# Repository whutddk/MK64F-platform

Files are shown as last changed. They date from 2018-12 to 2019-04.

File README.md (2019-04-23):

# mk64f-platform

A PCB platform of Arm (NXP-Kinetis) + FPGA (Xilinx-Aritx-7)

------------------------------------

### Construction
* doc 
  - designDoc(some document from manufacturer may be replaced by link )
  - referDoc(introduce of the board and design requirement)
* outputFile (output design file as pdf format)
* PCB(altium designer source file)

### Version List
* 0-1
* 0-2
* 0-3
* 0-4
* 1-1
* 1-3-5
* 3-1
* 4-3-2
* 4-3-5
* 5-2-0

##  Apache 2.0 for all and only my design

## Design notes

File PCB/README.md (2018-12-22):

# mk64f-platform

## place all pcb file here

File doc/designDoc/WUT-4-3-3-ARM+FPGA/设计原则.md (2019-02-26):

# Arm+FPGA原理验证

* 新设计需求
    - 摄像头CSI接口
    - 斩波电源

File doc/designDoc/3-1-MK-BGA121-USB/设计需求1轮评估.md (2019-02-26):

# USB迷你平台第一轮评估

* JTAG-mini10接口

* USB
    - MK64F公头

* 附加外设接口
    - CAN接口仅排针

* 电源
    - USB

* 外设
    - LED
    - 按键
    - 拨码开关

* 封装 
    - BGA
    - 小qfp

* PMOD
    - 完整全功能

* 可选项
    - 小Arduino排针口
    - TF卡口

* 尽量两层板摆平

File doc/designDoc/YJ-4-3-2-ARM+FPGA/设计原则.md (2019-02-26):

# Arm+FPGA原理验证

* 制作原型试验版，flexbus大面积布线
    - **流出总线信号测试口**，需要给测试报告
* 主要是挂载FPGA作为控制外设
    - 采用32bit地址加32bit数据形式
    - flexbus时钟同步
* 参考实现学长3种拓扑的可能性
* 扩大封装。减小焊接难度
    - 注意QSPIflash的封装问题
* 需要DONE INIT 验证初始化
* SPI下载 
* 一步到位，使用最高性能
    - 封装
    - 扇出
    - 总线时钟
* 标准实验
    - SRAM 映射
    - MCU控制fpga上模拟外设
    - 考虑作为协处理器ip加速读写实现问题

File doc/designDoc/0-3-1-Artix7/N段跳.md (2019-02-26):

# FPGA_N段跳

## FP3A_031
* 4mil/6mil 大部分
* 小部分使用3.5mil/3.5mil           嘉立创验证工艺
* 过孔0.2/0.45                        嘉利创验证工艺
* 焊盘到线5mil
* LDO 延时启动

---------
###测试目标
* **正常上电，先不贴保险**
* **JTAG下载，逻辑可实现**
* **QSPI引导**
* 外置MUC的spi引导
* 尝试SRAM 逻辑
* 

##FP3A_032
* 全面使用3.5mil/3.5mil
* 焊盘到线5mil
* BUCK斩波
* 强化扇出
* 等长
* 根据031情况考虑再测试及FLEXBUs挂载方式（下载方案？）

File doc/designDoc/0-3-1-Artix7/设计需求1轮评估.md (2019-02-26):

# 控制平台评估
## FPGA最小系统验证

* 设计参考开发板：Cmod A7-35T Artix-7
    - 主芯片 XC7A35T-1CPG236C ( 10*10 0.5 PITCH )

* 评估主芯片 
    - XC7A15T-1CSG325C 淘宝 138 ( 15*15 0.8 PITCH )
    - XC7A35T-2FTG256C 立创商城151 ( 17*17 1.0 PITCH )
    ~~ - XC7A35T-2FGG484I 云汉芯城 20片起订 127 ~~ 
    - XC7A35T-2FTG256C 华强旗舰 148 ( 17*17 1.0 PITCH )

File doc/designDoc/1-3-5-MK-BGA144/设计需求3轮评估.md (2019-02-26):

# 通用平台第三轮评估

* 内存块

* 缓冲 BGA54
* K64主时钟
    - 50M有源
    ~~- 8M无源~~
* 下载接口标准
    - swd
    - 
* 无源元件封装
    - 0805
    - 0603
    - 更小？
* USB
    - PWR
    - ID
    - usb 稳压器
    - FT2232 93C46如何预编程？
* 特殊外设接口
    - IR?
    - I2C
    - SPI
    - UART
    - CMP
    - ADC
        + 未使用接地
    - DAC
    - CAN
    - I2S
* 稳压器
    - 1117
    - 更小封装
    - 干脆不要
* thread选型
* 时钟
    - 单路
        + 来源？
    - 双路

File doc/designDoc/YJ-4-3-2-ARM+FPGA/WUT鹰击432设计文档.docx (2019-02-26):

# ARM+FPGA专用开发平台

# ——YJ 4-3-2设计文档

##### 鉴湖：李锐戈

## 1设计需求

设计一款专用开发平台，使其满足以下要求：

- ARM+FPGA架构
- FPGA作为存储器，通过Flexbus挂载在ARM上
- 使用最高冗余连接
- ARM可以配置FPGA
- 选型满足最新趋势及发展要求

尽量满足要求：

- ROM、RAM足够大
- 迷你板
- 引出IO数量及合理性满足开发需求
- 功耗

系统板命名方式：

- 此版本为硬件方向推进型号：按照惯例使用鹰击标志（YJ）。
- 此版本为整个项目第四大类：使用版本4。
- 这是第三块带YJ标志的PCB板：使用3作为子版本号。
- 此版本修正第2次：末尾标2。

## 2图纸分布

根据需求，设计原理图有8张。分别为：汇总图纸，系统电源，FPGA电源，FPGA配置，FPGA输入输出，处理器，SRAM配置，系统IO。

## 3电源设计说明

### 3.1电源输入

系统电源有三个输入：USB0输入，raspberry-HAT输入，Arduino-Shiel输入。输入电压范围4.8V-5.5V。常规使用三者选其一输入，违规使用情况下可能发生多个输入同时接入情况。因二极管存在，USB电源不能流向排针排座电源接口

### 3.2选型

- LDO：TLV71210
  - 600mA峰值输出，SOT-23-5小封装。
  - 0.5V压降
- LDO:TPS70151
  - 上电时序管理：RC延时启动1.8V，自动延时启动3.3V
  - 使能端负逻辑

## 4 MCU设计说明

### 4.1最小系统

K64最小系统设计参考WUT1-3-5。

- 采用50MHz有源晶振作为系统主时钟。
- 不使用USB稳压器

### 4.2外设扩展

MCU扩展外设包括：FlexBus，SDIO，SPI，I2C，I2S, FTM，USB，ADC，DAC，UART。

## 5 FPGA设计说明

FPGA设计参考FP3A 0-3-1设计。

### 5.1基本信息

参考CMod-A7的设计图纸，考虑采购成本等，选用XC7A34T-1FTG256作为核心器件。

第一批采购成本：102元/片

- XC7A35T
  - Xilinx Artix-7系列
  - Vivado 支持
  - 33,280 Logic Cells
  - 5,200 Slices
  - 400 Kb Distributed RAM
  - 90 DSP48E1 Slices
  - 100 * 18Kb + 50 * 36 Kb MAX 1800Kb BRAM
  - 5 CMTs
  - 1 PCle
  - 4 GTPS
  - 1 XADC
  - 5 I/O Banks
  - 250 user I/O
- 1FTG256封装
  - 无GTP
  - 5 BANK：BANK0，BANK14，BANK15，BANK34，BANK35
  - 170 I/O
  - 17mm * 17mm
  - Ball Pitch 1.0mm

### 5.2系统设计

#### 5.2.1 配置方式

使用1K电阻进行设定配置

前期Boot接法：

Mode0 = 1；

Mode1 = 0；

Mode1 = 0；

使用外部Qspi-flash进行配置，同时可以使用JTAG进行配置。

技术成熟后Boot接法：

Mode0 = 1；

Mode1 = 1；

Mode1 = 1；

使用MCU SPI2进行配置：

PTD7 = I/O 读取FPGA INIT

PTD10 = I/O 读取 FPGA DONE

PTD11 = SPI2 PCS0 未作使用

PTD12 = SPI2 SCK 作为时钟

PTD13 = SPI2 SOUT 作为数据输入

PTD14 = SPI2 SIN 未作使用

PTD15 = SPI2_PCS1 作为I/O触发FPGA PROG

同时可以使用JTAG进行配置。

#### 5.2.2 BANK配置

为满足I/O使用需求，所有BANK使用3.3V的电源。

为降低功耗，可以定制低BANK电压的型号。

#### 5.2.3 时钟源

FPGA具有4个BANK,设计了三个外部时钟源：

- BANK14 MRCC(N11)：GCLK，来源于外部有源晶振设计速度100MHz
- BANK15 MRCC(D13) ：MCU_CLK_OUT，来源于MCU的CLK_OUT口，主要作为flexbus辅助时钟，设计速度40MHz
- BANK35 MRCC(F5)：XCLK，来源于外部有源晶振，设计速度50MHz。

## 6 系统I/O

### 6.1 PS端设定I/O

- TF卡：PTE0、PTE1、PTE2、PTE3、PTE4、PTE5
- USB：USBP、USBN
- 有源蜂鸣器：PTE26
- 用户按键：PTE27
- 用户拨码开关：PTA6、PTA7

### 6.2 PS端扩展I/O

- PMOD4：DAC、PTE24、PTE25、RTC_WAKE
- Shiel-A：ADC*11+DAC*1
- Shiel-B：PTE8、PTE9、PTE10、PTE6、PTE7、PTE12、PTE11、PTE28
- Shiel-C：PTA9、PTA8、PTA11、PTA10、PTA19、PTA5、PTA15、PTA14、PTA17、PTA24、PTA25、PTA16、PTA12、PTA26、PTA13、PTA27
- Shiel-D：PTA29、PTA28、PTB1、PTB0、PTB3、PTB2、PTB5、PTB4

### 6.3 PL端设定I/O

- LED：K13(B)、L14(R)、L13(G)
- 无源蜂鸣器：M12
- 用户按键：K12
- 用户拨码开关：P5、N4
- Flexbus

D10 | AD14
C8 | AD22
C9 | OE
A8 | AD23
A9 | AD18
B9 | AD15
A10 | AD29
B10 | AD28
B11 | AD13
B12 | AD20
A12 | AD21
D9 | AD19
A13 | AD16
A14 | AD30
C14 | AD6
B14 | AD10
B15 | AD5
A15 | AD9
C16 | AD25
B16 | AD26
C11 | AD12
C12 | AD17
D13 | CLK-OUT
C13 | AD31
E12 | AD4
E13 | AD11
D14 | BE31_24
D15 | BE15_8
E16 | AD8
D16 | CS0
F15 | AD27
E15 | AD7
H13 | AD3
G14 | BE23_16
F14 | RW
H16 | BE7_0
G16 | AD24
J15 | AD0
J16 | AD1
H14 | AD2
G15 | ALE

- SRAM

B5 | DQ6
A5 | DQ4
A4 | DQ7
B4 | AD11
A3 | AD10
C3 | AD8
C2 | AD18
B2 | AD9
A2 | AD13
C1 | AD19
B1 | AD12
E2 | AD17
D1 | DQ15
E3 | DQ14
D3 | DQ13
D4 | DQ5
C4 | WR
F4 | AD15
F3 | DQ9
F2 | DQ11
E1 | DQ12
G5 | AD14
G4 | OE
G2 | DQ10
G1 | DQ8
H5 | AD16
H4 | AD5
J5 | AD6
J4 | AD2
H2 | AD4
H1 | AD0
J3 | CS
H3 | AD3
K1 | DQ0
J1 | AD1
L3 | AD7
L2 | DQ3
K3 | DQ2
K2 | DQ1

### 6.4 PL端扩展I/O

- HAT：M16、M14、N14、N16、N13、P15、P16、R16、T15、R15、T14、P14、T13、P13、R12、R13、T12、P11、N12、R11、T10、P10、R10、P9、T9、T8、N9、R8。（BANK14）
- PMOD1：R6、R7、T7、P8、M6、R5、T5、P6。（BANK14）
- PMOD2：M4、N3、M5、T4、R2、T2、R3、T3。（BANK34）
- PMOD3：P1、P3、P4、P1、M1、M2、N1、N2。（BANK34）
- Shiel-D2：A7、B7、D6、C7、C6、B6、E6、D5、K5、F5、L5、L4。（BANK34、BANK35）

## 7 测试

### 7.1功耗

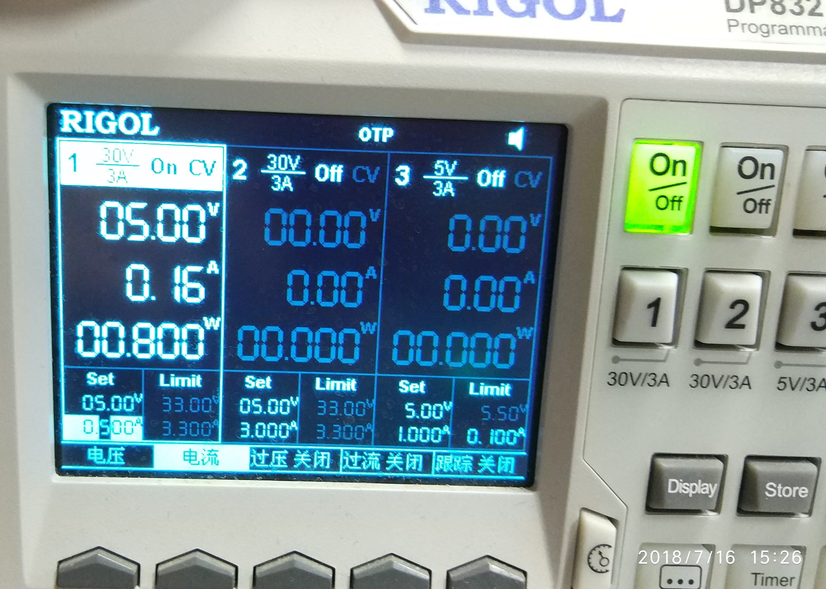
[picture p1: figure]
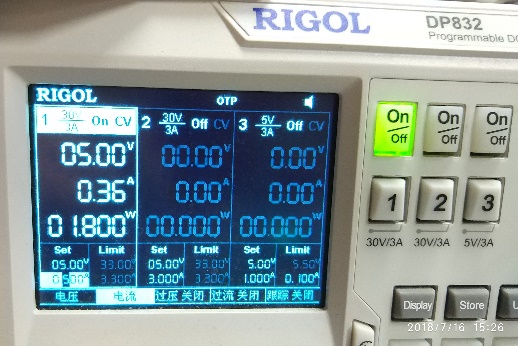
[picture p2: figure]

### 7.2 发热

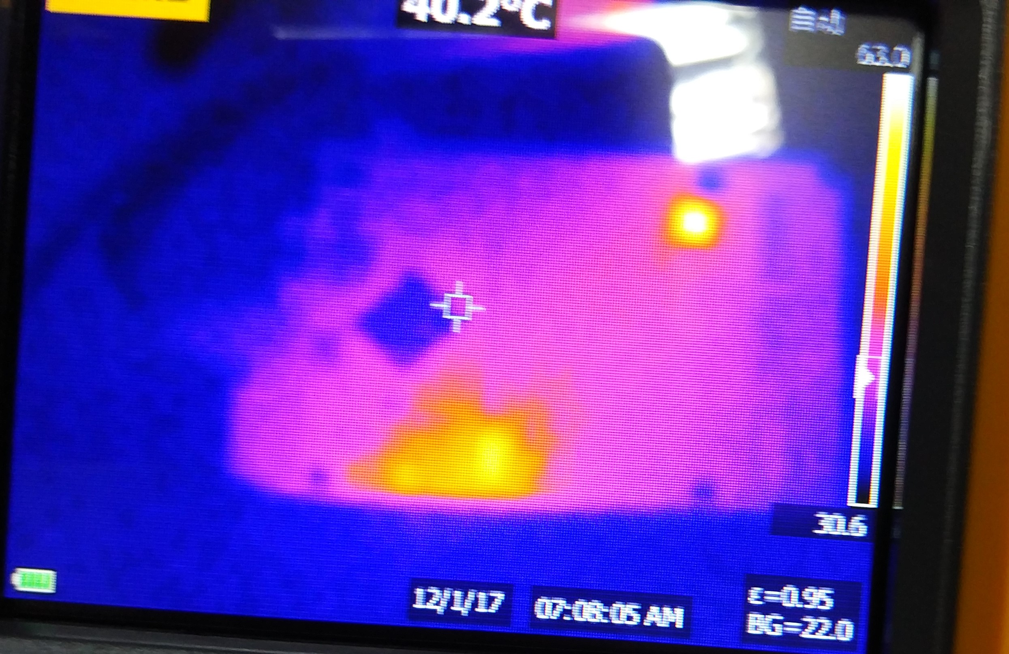
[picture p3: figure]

### 7.3信号

## 8 内部电路设计

### 8.1 PS+PL模式

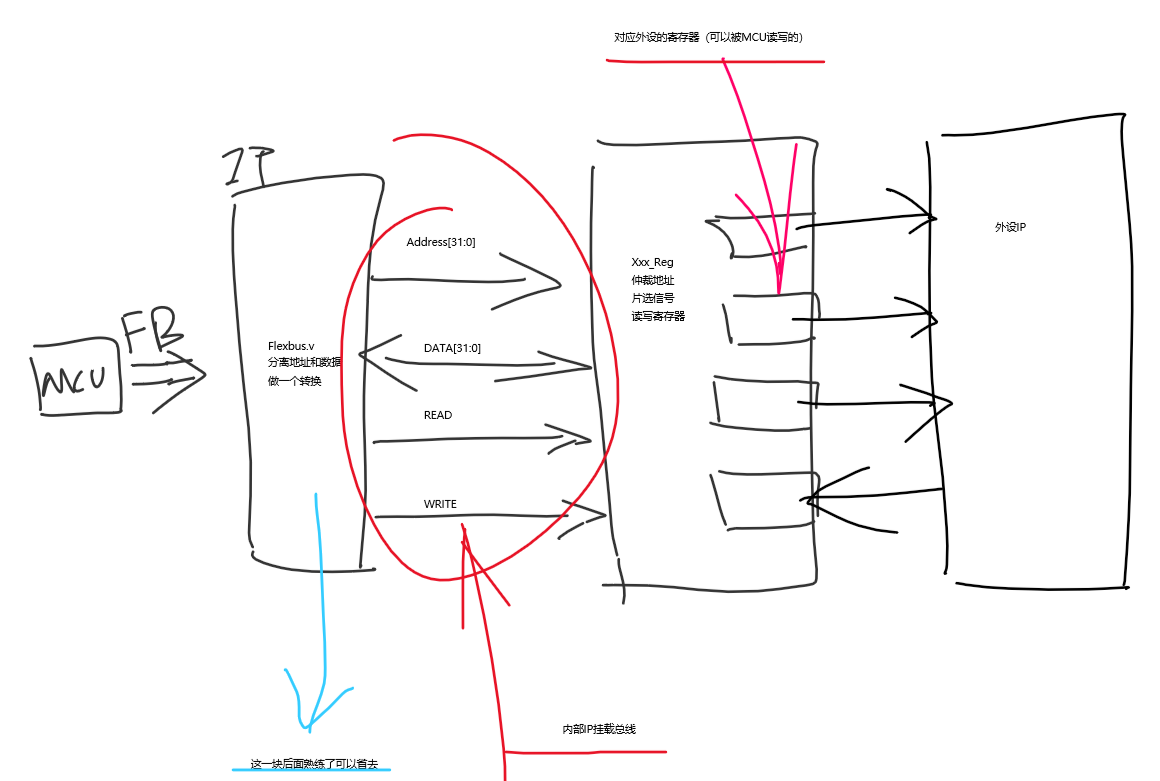
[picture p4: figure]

### 8.2 PL内部协同模式

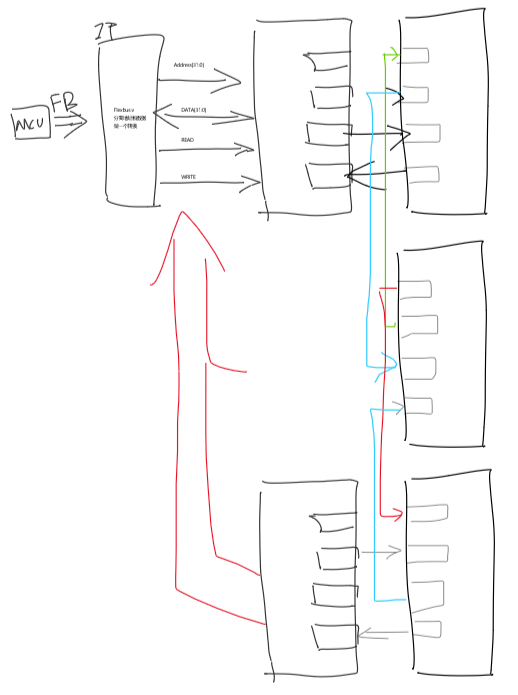
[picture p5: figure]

9设计仓链接

PCB：https://gitee.com/whutddk/MK64F-platform/tree/V4.3.0/ （私有，可查看镜像）

PL: https://gitee.com/whutddk/YJ432-PL

PS-OS: https://gitee.com/whutddk/yj431-mbedos

PS：https://gitee.com/whutddk/YJ431-PS

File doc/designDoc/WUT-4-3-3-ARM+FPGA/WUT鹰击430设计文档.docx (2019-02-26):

# ARM+FPGA专用开发平台

# ——YJ 4-3-0设计文档

##### 李锐戈

## 1设计需求

设计一款专用开发平台，使其满足以下要求：

- ARM+FPGA架构
- FPGA作为存储器，通过Flexbus挂载在ARM上
- 使用最高规格连接
- ARM可以配置FPGA
- 选型满足最新趋势及发展要求

尽量满足要求：

- ROM、RAM足够大
- 迷你板
- 引出IO数量及合理性满足开发需求
- 功耗

系统板命名方式：

- 此版本为推进型号：使用鹰击标志（YJ）。
- 此版本为整个项目第四大类：使用版本4。
- 这是第三块带YJ标志的PCB板：使用3作为子版本号。
- 此版本尚未进行修正：末尾标0。

## 2图纸分布

根据需求，设计原理图有8张。分别为：汇总图纸，系统电源，FPGA电源，FPGA配置，FPGA输入输出，处理器，SRAM配置，系统IO。

## 3电源设计说明

#### 3.1.1电源输入

系统电源有三个输入：USB0输入，raspberry-HAT输入，Arduino-Shiel输入。输入电压范围4.8V-5.5V。常规使用三者选其一输入，违规使用情况下可能发生多个输入同时接入情况。

#### 3.1.2负载需求

#### 3.1.3电源保护

负载电源：5V，3.3V。

3.1.5选型

- LDO：TLV71210
  - 600mA峰值输出，SOT-23-5小封装。
  - 0.5V压降
- LDO:TPS70151
  - 上电时序管理
  - 使能端负逻辑
- 肖特基选型：S4[In5817]（1206）
  - 1A
  - 20V

## 4 MCU设计说明

#### 3.2.1最小系统

K64最小系统设计参考WUT1-3-5。

- 采用50MHz有源晶振作为系统主时钟。
- 不使用USB稳压器

#### 3.2.2外设扩展

MCU扩展外设包括：FlexBus，SDIO，SPI，I2C，I2S, FTM，USB，ADC，DAC，UART。

## 5 FPGA设计说明

FPGA设计参考FP3A 0-3-1设计。

### 5.1基本信息

参考CMod-A7的设计图纸，考虑采购成本等，选用XC7A34T-1FTG256作为核心器件。

第一批采购成本：102元/片

- XC7A35T
  - Xilinx Artix-7系列
  - Vivado 支持
  - 33,280 Logic Cells
  - 5,200 Slices
  - 400 Kb Distributed RAM
  - 90 DSP48E1 Slices
  - 100 * 18Kb + 50 * 36 Kb MAX 1800Kb BRAM
  - 5 CMTs
  - 1 PCle
  - 4 GTPS
  - 1 XADC
  - 5 I/O Banks
  - 250 user I/O
- 1FTG256封装
  - 无GTP
  - 5 BANK：BANK0，BANK14，BANK15，BANK34，BANK35
  - 170 I/O
  - 17mm * 17mm
  - Ball Pitch 1.0mm

### 5.2系统设计

#### 5.2.1 配置方式

使用1K电阻进行设定配置

前期Boot接法：

Mode0 = 1；

Mode1 = 0；

Mode1 = 0；

使用外部Qspi-flash进行配置，同时可以使用JTAG进行配置。

技术成熟后Boot接法：

Mode0 = 1；

Mode1 = 1；

Mode1 = 1；

使用MCU SPI2进行配置：

PTD7 = I/O 读取FPGA INIT

PTD10 = I/O 读取 FPGA DONE

PTD11 = SPI2 PCS0 未作使用

PTD12 = SPI2 SCK 作为时钟

PTD13 = SPI2 SOUT 作为数据输入

PTD14 = SPI2 SIN 未作使用

PTD15 = SPI2_PCS1 作为I/O触发FPGA PROG

同时可以使用JTAG进行配置。

5.2.2 BANK配置

为满足I/O使用需求，所有BANK使用3.3V的电源。

为降低功耗，可以定制低BANK电压的型号。

5.2.3 时钟源

FPGA具有4个BANK,设计了三个外部时钟源：

- BANK14 MRCC(N11)：GCLK，来源于外部有源晶振设计速度100MHz
- BANK15 MRCC(D13) ：MCU_CLK_OUT，来源于MCU的CLK_OUT口，主要作为flexbus辅助时钟，设计速度60MHz
- BANK35 MRCC(F5)：XCLK，来源于外部有源晶振，设计速度50MHz。

## 6 系统I/O

## 6.1 PS端设定I/O

- TF卡：PTE0、PTE1、PTE2、PTE3、PTE4、PTE5
- USB：USBP、USBN
- 有源蜂鸣器：PTE26
- 用户按键：PTE27
- 用户拨码开关：PTA6、PTA7

### 6.2 PS端扩展I/O

- PMOD4：DAC、PTE24、PTE25、RTC_WAKE
- Shiel-A：ADC*11+DAC*1
- Shiel-B：PTE8、PTE9、PTE10、PTE6、PTE7、PTE12、PTE11、PTE28
- Shiel-C：PTA9、PTA8、PTA11、PTA10、PTA19、PTA5、PTA15、PTA14、PTA17、PTA24、PTA25、PTA16、PTA12、PTA26、PTA13、PTA27
- Shiel-D：PTA29、PTA28、PTB1、PTB0、PTB3、PTB2、PTB5、PTB4

### 6.3 PL端设定I/O

- LED：K13(B)、L14(R)、L13(G)
- 无源蜂鸣器：M12
- 用户按键：K12
- 用户拨码开关：P5、N4
- Flexbus

D10 | AD14
C8 | AD22
C9 | OE
A8 | AD23
A9 | AD18
B9 | AD15
A10 | AD29
B10 | AD28
B11 | AD13
B12 | AD20
A12 | AD21
D9 | AD19
A13 | AD16
A14 | AD30
C14 | AD6
B14 | AD10
B15 | AD5
A15 | AD9
C16 | AD25
B16 | AD26
C11 | AD12
C12 | AD17
D13 | CLK-OUT
C13 | AD31
E12 | AD4
E13 | AD11
D14 | BE31_24
D15 | BE15_8
E16 | AD8
D16 | CS0
F15 | AD27
E15 | AD7
H13 | AD3
G14 | BE23_16
F14 | RW
H16 | BE7_0
G16 | AD24
J15 | AD0
J16 | AD1
H14 | AD2
G15 | ALE

- SRAM

B5 | DQ6
A5 | DQ4
A4 | DQ7
B4 | AD11
A3 | AD10
C3 | AD8
C2 | AD18
B2 | AD9
A2 | AD13
C1 | AD19
B1 | AD12
E2 | AD17
D1 | DQ15
E3 | DQ14
D3 | DQ13
D4 | DQ5
C4 | WR
F4 | AD15
F3 | DQ9
F2 | DQ11
E1 | DQ12
G5 | AD14
G4 | OE
G2 | DQ10
G1 | DQ8
H5 | AD16
H4 | AD5
J5 | AD6
J4 | AD2
H2 | AD4
H1 | AD0
J3 | CS
H3 | AD3
K1 | DQ0
J1 | AD1
L3 | AD7
L2 | DQ3
K3 | DQ2
K2 | DQ1

### 6.4 PL端扩展I/O

- HAT：M16、M14、N14、N16、N13、P15、P16、R16、T15、R15、T14、P14、T13、P13、R12、R13、T12、P11、N12、R11、T10、P10、R10、P9、T9、T8、N9、R8。（BANK14）
- PMOD1：R6、R7、T7、P8、M6、R5、T5、P6。（BANK14）
- PMOD2：M4、N3、M5、T4、R2、T2、R3、T3。（BANK34）
- PMOD3：P1、P3、P4、P1、M1、M2、N1、N2。（BANK34）
- Shiel-D2：A7、B7、D6、C7、C6、B6、E6、D5、K5、F5、L5、L4。（BANK34、BANK35）

## 6外扩RAM设计说明

外扩RAM参考MAPS-K64设计，采用FlexBus驱动SN74LVC16373A锁存器和EM7164SU16，1M*16bit外部SRAM。

#### 3.4.1接线

##### 3.4.1.1地址线

该SRAM有1M寻址范围，有20根地址线。

其中A0-A14，15根地址线通过锁存器接到FlexBus的FB_AD1-AD15。（FlexBus的FB_AD0接入锁存器后作为输出测试点输出，即悬空）

A15-A19,直接接到FlexBus的FB_AD16-AD20。

##### 3.4.1.2数据线

16bit SRAM有16条数据线，DQ0-DQ15直接接到FLexBus的FB_AD0-AD15。

##### 3.4.1.3控制线

SRAM端 | 描述 | 接线
/ZZ | 低功耗 | H（3.3V）
DNU | NC | NC
/UB | 高8位 | BE31_24
/LB | 低8位 | BE23_16
/OE | 输出使能 | FB_OE
/WE | 写使能 | FB_WE
/CS | 片选 | FB_CS2
1LE 2LE | 锁存 | FB_ALE
1/OE 2/OE | 输出使能 | L（GND）

注：需要注意的是MK64FlexBus必须使能CS0才可以使用，测试版本遵照MAPS-K64原理图，使用的是CS2但操作FlexBus时仍然需要使能CS0。

#### 3.4.2时序

状态机：

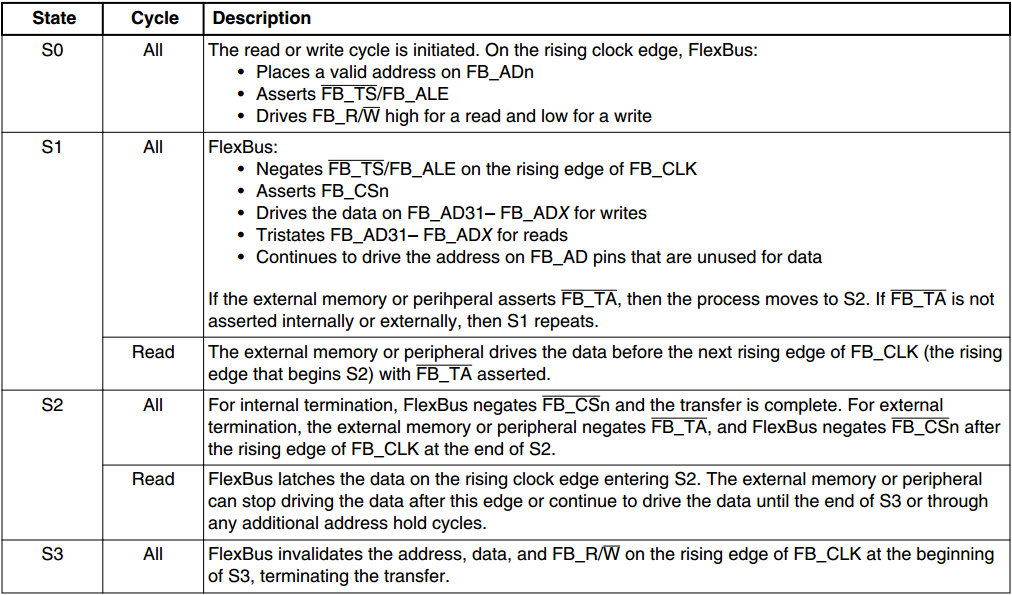
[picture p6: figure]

读时序：

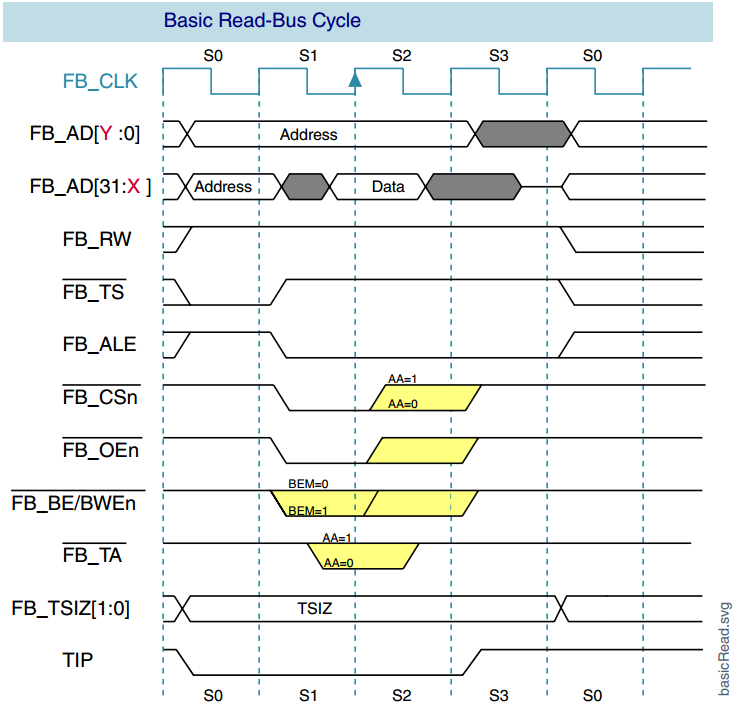
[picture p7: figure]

写时序：

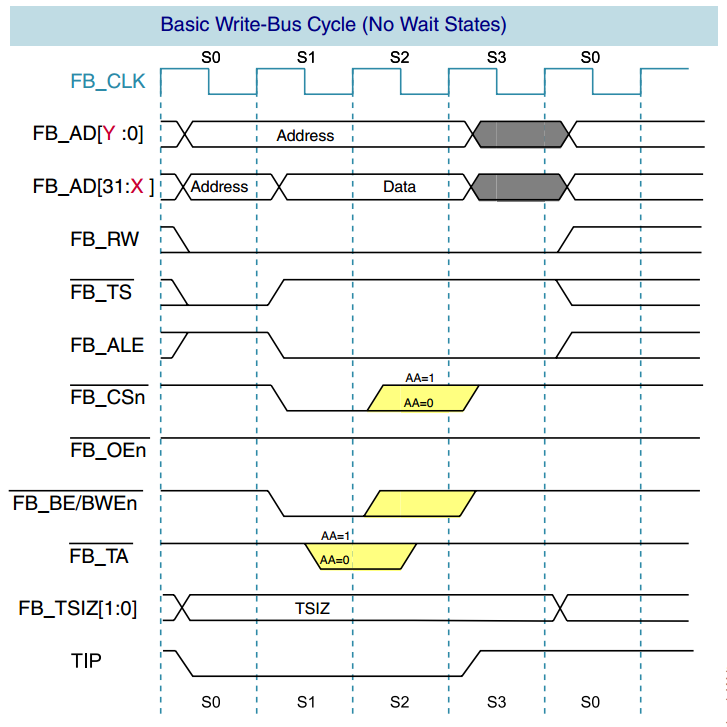
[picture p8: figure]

#### 3.4.3 Memory Map

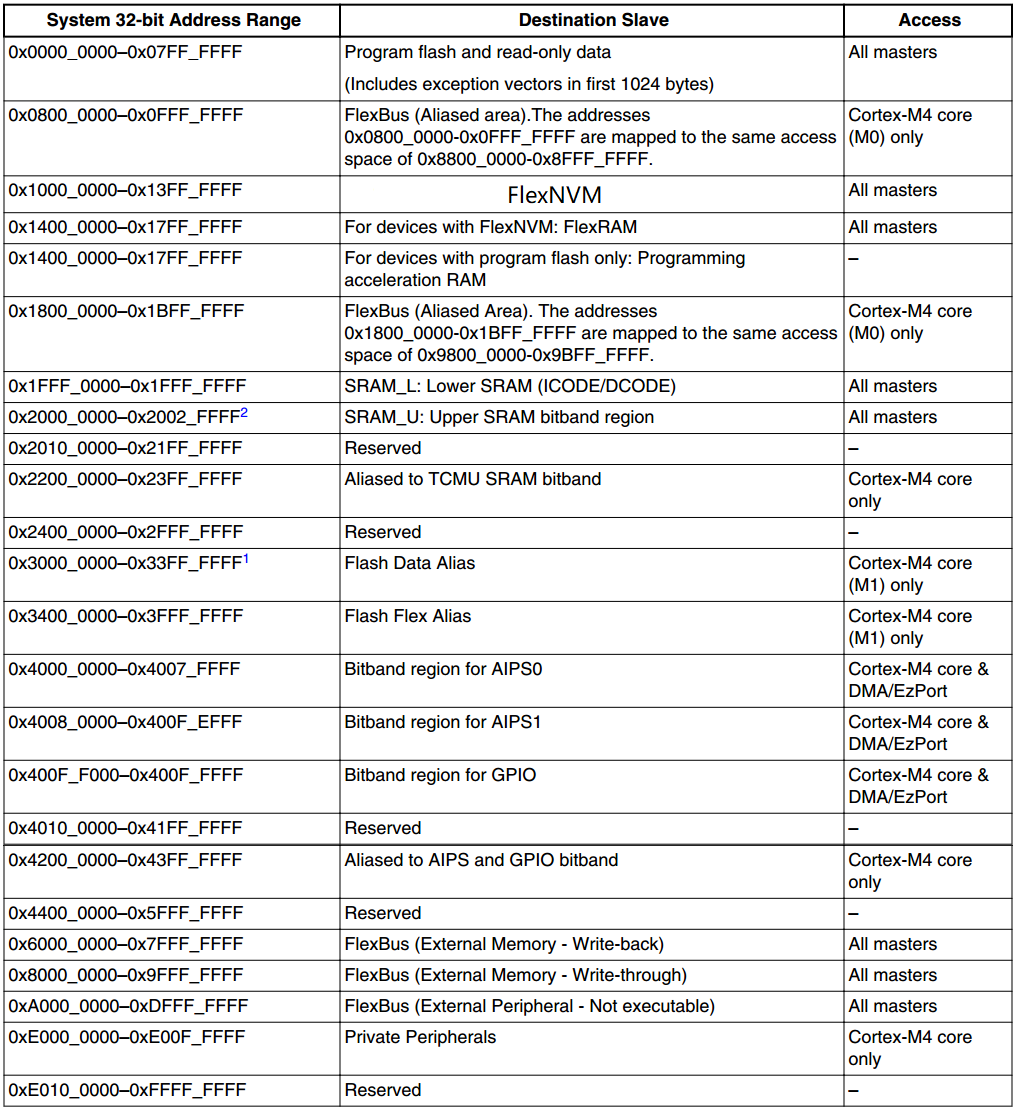
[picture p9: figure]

### 3.5外扩接口设计说明

外扩接口建议采用Arduino接口，除电源类引脚外，其余引脚分配以方便布线为标准分配。

Arduino接口1 ：

I2C：PTB0,PTB1,PTB2,PTB3

PWM：PTB0,PTB1

QEI：PTB0,PTB1

三线制SPI：PTB20,PTB21,PTB22

PTB20 | SPI2_PCS0 | PTB7 | ADC LED
PTB21 | SPI2_SCK | PTB6 | ADC
PTB22 | SPI2_SOUT | PTB3 | ADC I2C0_SDA UART0_CTS_B/COL_B FTM0_FLT0
NC | | PTB2 | ADC I2C0_SCL UART0_RTS_B FTM0_FLT3
RTC_INT | RTC唤醒输出 | PTB1 | ADC I2C0_SDA FTM1_CH1 FTM1_QD_PHB
PTA29 | IO | PTB0 | ADC I2C0_SCL FTM1_CH0 FTM1_QD_PHA

Arduino电源接口：

NC | | NC
3.3V | | 3.3V
RESET | | RESET
3.3V | | 3.3V
VCC | | VCC
GND | | GND
GND | | GND
VCC | | VCC

Arduino接口3：

四线制SPI：PTD11,PTD12,PTD13,PTD14,PTD15

PWM：PTE6,PTD7

PTD7 | UART0_TX FTM0_CH7 FTM0_FLT1 SPI1_SIN | NC
PTD10 | UART5_RTS_B | NC
PTD11 | SPI2_PCS0 UART5_CTS_B | NC
PTD12 | SPI2_SCK FTM3_FLT0 | NC
PTD13 | SPI2_SOUT | NC
PTD14 | SPI2_SIN | NC
PTD15 | SPI2_PCS1 | NC
PTE6 | SPI1_PCS3UART3_CTS_B I2S0_MCLK FTM3_CH1 | NC

Arduino接口4：

ADC,DAC

ADC0_DP1 | NC
ADC0_DM1 | NC
ADC1_DP1 | NC
ADC1_DM1 | NC
ADC0_DP0/ADC1_DP3 | NC
ADC0_DM0/ADC1_DM3 | NC
ADC1_DP0/ADC0_DP3 | ADC0_SE16 ADC0_SE21
ADC1_DM0/ADC0_DM3 | ADC1_SE16 ADC0_SE22
GND | DAC0 ADC0_SE23
VREF_OUT ADC1_SE18 | DAC1 ADC1_SE23

### 3.6 PMOD接口设计说明

PMOD接口主要为802.15.4接口MRF24J40表贴模块设计以热转印法覆铜板蚀刻方便为标准进行接口排序，同时兼顾I2S需求引脚。

作为四线制SPI可直接使用

作为I2S接口

UART0:PTA14,PTA15

PMOD：

PTA17 | SPI0_SIN ADC UART0_RTS_B I2S_MCLK | PTA5 | IO/INT FTM0_CH2 I2S_TX_BCLK
PTA15 | SPI0_SCK UART0_RX I2S0_RXD0 | PTA12 | IO/WAKE`FTM1_CH0 I2C2_SCL`I2S0_TXD0`FTM1_QD_A
PTA16 | SPI0_SOUT UART0_CTS_B/COL_B I2S0_RX_FS I2S_RXD1 | NC
PTA14 | SPI0_PCS0 UART0_TX I2C2_SCL I2S0_RX_BCLK I2S0_TXD1 | PTA13 | FTM1_CH1 I2C2_SDA I2S0_TX_FS FTM1_QD_PHB
GND | | GND
3.3V | | 3.3V

## 4布线标准

### 4.1线宽

该线路板仅为物联网应用设计，因此布线线宽不考虑大功率大电流场合。

GND最大线宽20mil。

电源类最大线宽15mil。

信号类线宽5~10mil。

### 4.2等长线

FlexBus设计时钟速度30MHz，实际SRAM信号速度小于15MHz。参考MAPS-K64的布线，没有采用等长走线方式。

### 4.3板层

参考K64手册布线建议，4层板分配如下：

Top Layer：走主要信号线，放置主要元件。

GND Plane：地平面

Mid Layer：为Bottom Layer重要信号线铺地。次要信号线，辅助BGA扇出，辅助跳线。

Bottom Layer：走主要信号线，尽量少放元件。

## 5测试方案（使用鉴湖规范）

0版本主要为技术验证，需要验证的的技术如下：

- MK64最小系统
- FT2232可行性
- SRAM可行性及极限速度带宽
- 电源可用性
- 电源质量

### 5.1 MK64最小系统独立测试

1) 在仅贴装MK64的情况下，通过JTAG排针口供电并进行连接，下载。
2) 如能完成上一步，贴入高速晶振，复位电路，PTA4，EZport上拉电阻进行代码运行测试。
3) 如可以完成上一步，则可以接入模拟电源，RTC时钟等进行全部功能测试。

### 5.2 FT2232D测试

1) 如MK64最小系统测试通过，测可以直接通过MK64对FT2232进行测试。
2) 如MK64测试未通过，FT2232串口可以通过测试焊盘测试。
3) 如MK64测试未通过，FT2232的JTAG协议可以通过以下两种方式进行测试：
a) JTAG排针接口和另外的处理器进行连接验证可用性。
b) JTAG排针接口与SN74BCT8244A进行详细测试。

### 5.3 SRAM测试

该测试需要在MK64可用情况下进行代码测试。

### 5.4电源测试

5V输入和3.3V输入各带一个自恢复保险，可以拿掉保险管进行空载测试。

其余可以按需求进行测试。

### 5.5整块电路板测试顺序（参照鉴湖实验室测试规范）

i. MCU不带晶振系统测试
ii. MCU带晶振最小系统测试（仅做一次）
iii. MCU带RAM低速通信测试（仅做一次）
iv. 电源独立测试（软起动）（仅做一次）
v. 整块电路电源软起动测试（每次必做）
vi. USB下载口功能测试（仅做一次）
vii. 其余外设测试（每次必做）

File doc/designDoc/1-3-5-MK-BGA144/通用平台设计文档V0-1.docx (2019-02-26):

# 通用平台设计文档V-0.1

##### 606-6 李锐戈

## 1设计需求

设计一款通用控制平台，使其满足以下要求：

- 支持mbed操作系统
- 满足物联网开发要求
  - 具有真随机数发生器
  - 具有加密模块
  - 支持thread开发
- 满足USB软件调试需求
- 基本兼容Arduino接口
- USB接口供电
- 方便扩展为ARM+FPGA结构

尽量满足要求：

- ROM、RAM足够大
- 低功耗
- 迷你板
- 低成本

## 2图纸分布

根据设计需求，图纸可以分为6大块。分别为：电源、MCU、Memory、外设接口、USB接口、射频模块。

## 3详细设计说明

### 3.1电源设计说明

电源模块包括系统电源和RTC电源，RTC电源并入系统电源中，不单独设计。

#### 3.1.1电源输入

系统电源有三个输入：USB0输入，USB1输入，Arduino接口输入。输入电压范围4.8V-5.5V。常规使用三者选其一输入，违规使用情况下可能发生多个输入同时接入情况。

#### 3.1.2负载需求

3.1.2.1电压需求

系统只有3.3V，5V的电压需求。

MK64：3.3V

50M有源晶振：3.3V

外部RAM：3.3V

锁存器：3.3V

TF卡：3.3V

MRF24J40：3.3V

FT2232：5V+3.3V

AT93C46：1.8-5.5V

3.1.2.2功耗需求统计：260mA

5V线性稳压耗散功率0.5W。

MK64：内核40mA IO 100mA

外部RAM：25mA

锁存器：0.02mA

MRF24J40：19-23mA

FT2232：70mA

AT93C46：2mA

可以按300mA标准设计系统输入电源。

#### 3.1.3电源保护

3.1.3.1过流保护

系统整体功耗可以设计为300mA,即可放置300-500mA自恢复保险管于稳压器之前。可以避免因短路造成的过流损害。

3.1.3.2电源反接

USB供电口不存在反接问题。Arduino电源输入接口在极端违规操作下可发生电源反接。

自恢复保险管可以进行短时间保护。长时间反接不做保护。

3.1.3.3电流倒灌保护

电流不允许从5V流回USB，因此，USB电流输入口需要放置一个肖特基二极管，不允许电流倒灌。

3.1.3.4多电源保护

在违规操作情况下，可能发生USB与Ardurno电源同时接入的情况。当两边电压不完全一致时，将产生涡流。

5V电源由于USB带有肖特基二极管，可以耗尽电压差，因此不再做附加处理。

3.3V电源的Arduino接口需要放置一个大功率0欧电阻。用于在违规操作条件下平衡电压。

3.1.3.5负载冲击纹波保护

本设计中不存在大负载，因此纹波控制需求较低。仅选择在关键电源使用PI滤波器；关键负载使用钽电容滤波。仅使用模拟地隔离，不使用功率地隔离。

3.1.4电源拓扑

5V

系统电源命名如下：

电源输入：VBUS0，VBUS1，VCC。

3.3V

负载电源：5V，3.3V。

负载

拓扑图如下：

USB电源输入

VCC

LDO 自恢复保险

Arduino接口输入

自恢复保险

肖特基二极管

VBUS1

VBUS0

3.1.5选型

- LDO：MIC5219
  - 500mA峰值输出，SOT-23-5小封装。
  - 0.5V压降
- 肖特基选型：S4[In5817]（1206）
  - 1A
  - 20V

### 3.2 MCU设计说明

#### 3.2.1最小系统

K64最小系统设计参考MAPS-K64官方接法。

采用BGA121封装

- 采用50MHz有源晶振作为系统主时钟。
- 不使用USB稳压器

#### 3.2.2外设扩展

MCU扩展外设包括：FlexBus，SDIO，SPI,I2C,I2S, FTM,USB,ADC,DAC，UART。具体管脚分配在3.7中阐述。

### 3.3 USB调试设计说明

#### 3.3.1 USB接口

Micro-B （安卓口）

#### 3.3.2转换芯片

FT2232，采用LQFP封装
A功能定义为JTAG

B功能定义为串口：

PTE24:UART4_TX

PTE25:UART4_RX

其余接法参考数据手册

#### 3.3.3EEPROM

参考FT2232官方手册，第一版采用AT93C46作为其编程芯片。

### 3.4外扩RAM设计说明

外扩RAM参考MAPS-K64设计，采用FlexBus驱动SN74LVC16373A锁存器和EM7164SU16，1M*16bit外部SRAM。

#### 3.4.1接线

##### 3.4.1.1地址线

该SRAM有1M寻址范围，有20根地址线。

其中A0-A14，15根地址线通过锁存器接到FlexBus的FB_AD1-AD15。（FlexBus的FB_AD0接入锁存器后作为输出测试点输出，即悬空）

A15-A19,直接接到FlexBus的FB_AD16-AD20。

##### 3.4.1.2数据线

16bit SRAM有16条数据线，DQ0-DQ15直接接到FLexBus的FB_AD0-AD15。

##### 3.4.1.3控制线

SRAM端 | 描述 | 接线
/ZZ | 低功耗 | H（3.3V）
DNU | NC | NC
/UB | 高8位 | BE31_24
/LB | 低8位 | BE23_16
/OE | 输出使能 | FB_OE
/WE | 写使能 | FB_WE
/CS | 片选 | FB_CS2
1LE 2LE | 锁存 | FB_ALE
1/OE 2/OE | 输出使能 | L（GND）

注：需要注意的是MK64FlexBus必须使能CS0才可以使用，测试版本遵照MAPS-K64原理图，使用的是CS2但操作FlexBus时仍然需要使能CS0。

#### 3.4.2时序

状态机：


读时序：


写时序：


#### 3.4.3 Memory Map


### 3.5外扩接口设计说明

外扩接口建议采用Arduino接口，除电源类引脚外，其余引脚分配以方便布线为标准分配。

Arduino接口1 ：

I2C：PTB0,PTB1,PTB2,PTB3

PWM：PTB0,PTB1

QEI：PTB0,PTB1

三线制SPI：PTB20,PTB21,PTB22

PTB20 | SPI2_PCS0 | PTB7 | ADC LED
PTB21 | SPI2_SCK | PTB6 | ADC
PTB22 | SPI2_SOUT | PTB3 | ADC I2C0_SDA UART0_CTS_B/COL_B FTM0_FLT0
NC | | PTB2 | ADC I2C0_SCL UART0_RTS_B FTM0_FLT3
RTC_INT | RTC唤醒输出 | PTB1 | ADC I2C0_SDA FTM1_CH1 FTM1_QD_PHB
PTA29 | IO | PTB0 | ADC I2C0_SCL FTM1_CH0 FTM1_QD_PHA

Arduino电源接口：

NC | | NC
3.3V | | 3.3V
RESET | | RESET
3.3V | | 3.3V
VCC | | VCC
GND | | GND
GND | | GND
VCC | | VCC

Arduino接口3：

四线制SPI：PTD11,PTD12,PTD13,PTD14,PTD15

PWM：PTE6,PTD7

PTD7 | UART0_TX FTM0_CH7 FTM0_FLT1 SPI1_SIN | NC
PTD10 | UART5_RTS_B | NC
PTD11 | SPI2_PCS0 UART5_CTS_B | NC
PTD12 | SPI2_SCK FTM3_FLT0 | NC
PTD13 | SPI2_SOUT | NC
PTD14 | SPI2_SIN | NC
PTD15 | SPI2_PCS1 | NC
PTE6 | SPI1_PCS3UART3_CTS_B I2S0_MCLK FTM3_CH1 | NC

Arduino接口4：

ADC,DAC

ADC0_DP1 | NC
ADC0_DM1 | NC
ADC1_DP1 | NC
ADC1_DM1 | NC
ADC0_DP0/ADC1_DP3 | NC
ADC0_DM0/ADC1_DM3 | NC
ADC1_DP0/ADC0_DP3 | ADC0_SE16 ADC0_SE21
ADC1_DM0/ADC0_DM3 | ADC1_SE16 ADC0_SE22
GND | DAC0 ADC0_SE23
VREF_OUT ADC1_SE18 | DAC1 ADC1_SE23

### 3.6 PMOD接口设计说明

PMOD接口主要为802.15.4接口MRF24J40表贴模块设计以热转印法覆铜板蚀刻方便为标准进行接口排序，同时兼顾I2S需求引脚。

作为四线制SPI可直接使用

作为I2S接口

UART0:PTA14,PTA15

PMOD：

PTA17 | SPI0_SIN ADC UART0_RTS_B I2S_MCLK | PTA5 | IO/INT FTM0_CH2 I2S_TX_BCLK
PTA15 | SPI0_SCK UART0_RX I2S0_RXD0 | PTA12 | IO/WAKE`FTM1_CH0 I2C2_SCL`I2S0_TXD0`FTM1_QD_A
PTA16 | SPI0_SOUT UART0_CTS_B/COL_B I2S0_RX_FS I2S_RXD1 | NC
PTA14 | SPI0_PCS0 UART0_TX I2C2_SCL I2S0_RX_BCLK I2S0_TXD1 | PTA13 | FTM1_CH1 I2C2_SDA I2S0_TX_FS FTM1_QD_PHB
GND | | GND
3.3V | | 3.3V

## 4布线标准

### 4.1线宽

该线路板仅为物联网应用设计，因此布线线宽不考虑大功率大电流场合。

GND最大线宽20mil。

电源类最大线宽15mil。

信号类线宽5~10mil。

### 4.2等长线

FlexBus设计时钟速度30MHz，实际SRAM信号速度小于15MHz。参考MAPS-K64的布线，没有采用等长走线方式。

### 4.3板层

参考K64手册布线建议，4层板分配如下：

Top Layer：走主要信号线，放置主要元件。

GND Plane：地平面

Mid Layer：为Bottom Layer重要信号线铺地。次要信号线，辅助BGA扇出，辅助跳线。

Bottom Layer：走主要信号线，尽量少放元件。

## 5测试方案（使用鉴湖规范）

0版本主要为技术验证，需要验证的的技术如下：

- MK64最小系统
- FT2232可行性
- SRAM可行性及极限速度带宽
- 电源可用性
- 电源质量

### 5.1 MK64最小系统独立测试

1) 在仅贴装MK64的情况下，通过JTAG排针口供电并进行连接，下载。
2) 如能完成上一步，贴入高速晶振，复位电路，PTA4，EZport上拉电阻进行代码运行测试。
3) 如可以完成上一步，则可以接入模拟电源，RTC时钟等进行全部功能测试。

### 5.2 FT2232D测试

1) 如MK64最小系统测试通过，测可以直接通过MK64对FT2232进行测试。
2) 如MK64测试未通过，FT2232串口可以通过测试焊盘测试。
3) 如MK64测试未通过，FT2232的JTAG协议可以通过以下两种方式进行测试：
a) JTAG排针接口和另外的处理器进行连接验证可用性。
b) JTAG排针接口与SN74BCT8244A进行详细测试。

### 5.3 SRAM测试

该测试需要在MK64可用情况下进行代码测试。

### 5.4电源测试

5V输入和3.3V输入各带一个自恢复保险，可以拿掉保险管进行空载测试。

其余可以按需求进行测试。

### 5.5整块电路板测试顺序（参照鉴湖实验室测试规范）

i. MCU不带晶振系统测试
ii. MCU带晶振最小系统测试（仅做一次）
iii. MCU带RAM低速通信测试（仅做一次）
iv. 电源独立测试（软起动）（仅做一次）
v. 整块电路电源软起动测试（每次必做）
vi. USB下载口功能测试（仅做一次）
vii. 其余外设测试（每次必做）

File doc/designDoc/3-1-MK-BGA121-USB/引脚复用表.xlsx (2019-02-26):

控制平台引脚复用表
引脚号 | 功能
排针座
ADC |  |  |  |  | PTD7
ADC |  |  |  |  | PTD6
ADC |  |  |  |  | PTC8
ADC |  |  |  |  | PTC7
ADC |  |  |  |  | PTC4
ADC |  |  |  |  | PTC3
DAC |  |  |  |  | PTD9
PTE25 | UART4 |  |  |  | PTC0
PTE24 | UART4 |  |  |  | PTD8
GND |  |  |  |  | PTB12
3.3V |  |  |  |  | PTB13
TMS |  |  |  |  | PTB11
TCK |  |  |  |  | PTB8
TDO |  |  |  |  | PTB10
TDI |  |  |  |  | PTB0 | I2C
n_RST |  |  |  |  | PTB1 | I2C
PMOD
PTA14 | SPI0_PCS0 | UART0_TX | I2S0_RX_BCLK | I2S0_TXD1 | PTA13 |  | I2S0_TX_FS
PTA16 | SPI0_SOUT |  | I2S0_RX_FS | I2S0_RXD1 | PTA12 | I2C2_SCL | I2S0_TXD0
PTA17 | SPI0_SIN |  | I2S0_MCLK |  | PTA11 | I2C2_SDA
PTA15 | SPI0_SCK | UART0_RX | I2S0_RXD0 |  | PTA5 | I2S_TX_BCLK
GND |  |  |  |  | GND
3.3V |  |  |  |  | 3.3V
拨码开关
PTB20
PTB6
PTB9
PTB7
LED
PTC13
PTC14
按键
PTA29

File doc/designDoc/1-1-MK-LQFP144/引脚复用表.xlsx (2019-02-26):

控制平台引脚复用表
引脚号 | 功能
arduino1-1 |  |  |  |  | Arduino1-2
PTB3 | I2C0_SDA | ADC |  |  | PTB4 | ADC | IO
PTB1 | I2C0_SDA | FTM1_QD_PHB | ADC |  | PTB2 | I2C0_SCL
PTA29 | IO |  |  |  | PTB0 | I2C0_SCL | FTM1_QD_PHA | ADC
PTA27 | IO |  |  |  | PTA28 | IO
PTA25 | IO |  |  |  | PTA26 | IO
PTA19 | LPTMR |  |  |  | PTA24 | IO
Arduino2-1 |  |  |  |  | Arduino2-2
VCC |  |  |  |  | PTA13 | CAN0_RX
GND |  |  |  |  | PTA12 | CAN0_TX
GND |  |  |  |  | PTA11 | FTM2_QD_PHB
VCC |  |  |  |  | PTA10 | FTM2_QD_PHA
3.3V |  |  |  |  | PTA9 | FTM1_QD_PHB
N_RST |  |  |  |  | PTA8 | FTM1_QD_PHA
3.3V |  |  |  |  | PTA7 | FTM0_CH4
NC |  |  |  |  | PTA6 | FTM0_CH3
Arduino3-1 |  |  |  |  | Arduino3-2
PTD7 | FTM0_CH7 | UART0_TX |  |  | PTD8 | UART5_RX | I2C0_SCL
PTD9 | UART5_TX | I2C0_SDA |  |  | PTD10 | IO
PTD11 | SPI2_PCS0 |  |  |  | PTD12 | SPI2_SCK
PTD13 | SPI2_SOUT |  |  |  | PTD14 | SPI2_SIN
PTD15 | SPI2_PCS1 |  |  |  | PTE6 | FTM3_CH1
PTE7 | FTM3_CH2 |  |  |  | PTE8 | FTM3_CH3
PTE9 | FTM3_CH4 |  |  |  | PTE10 | FTM3_CH5
PTE11 | FTM3_CH6 |  |  |  | PTE12 | FTM3_CH7
Arduino4-1 |  |  |  |  | Arduino4-2
ADC |  |  |  |  | ADC
ADC |  |  |  |  | ADC
ADC |  |  |  |  | ADC
GND |  |  |  |  | ADC
ADC |  |  |  |  | ADC
ADC |  |  |  |  | ADC
DAC |  |  |  |  | ADC
PTE24 | UART4_TX | I2C0_SCL |  |  | PTE25 | UART4_RX | I2C0_SDA
GND |  |  |  |  | PTE26 | IO
PTE27 | IO |  |  |  | PTE28 | IO
PMOD
PTA14 | SPI0_PCS0 | UART0_TX | I2S0_RX_BCLK | I2S0_TXD1 | PTA13 |  | I2S0_TX_FS
PTA16 | SPI0_SOUT |  | I2S0_RX_FS | I2S0_RXD1 | PTA12 | I2C2_SCL | I2S0_TXD0
PTA17 | SPI0_SIN |  | I2S0_MCLK |  | PTA11 | I2C2_SDA
PTA15 | SPI0_SCK | UART0_RX | I2S0_RXD0 |  | PTA5 | I2S_TX_BCLK
GND |  |  |  |  | GND
3.3V |  |  |  |  | 3.3V

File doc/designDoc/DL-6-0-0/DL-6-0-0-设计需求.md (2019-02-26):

# DL-6-0-0设计需求

* 快速投板，满足寒假开发需求
* 修复stm32 CMSIS-DAP usb布线的bug，再次尝试民间版本固件
* 有时间要尝试官方dap-link
* 复制小型化FT2232下载器，满足基本需求
* 需要SMT打样
* 改用大USB头
* 注意外壳接地
* 紧急投板

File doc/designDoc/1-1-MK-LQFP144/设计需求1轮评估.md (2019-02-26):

# 控制平台第一轮评估

* 内存块
    - 保留

* JTAG-mini10接口

* USB
    - ~~FT2232~~ 撤走
    - 仅调试供电

* 附加外设接口
    - CAN接口仅排针
    - 保留PMOD
    - 单引脚对应多接口
    - 软排线接口引出所有io

* 电源
    - 其余电源外部来
    - USB调试用供电

* 标准控制外设
    - 2*8chnpwm
    - 2*qei

* 传统调试接口
    - 外部来

* 先进调试接口
    - 外部来

* 电力变换
    - 外部来

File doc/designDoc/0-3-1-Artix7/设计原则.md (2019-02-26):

# FPGA最小系统验证

## 主芯片选型

----------------

1. 这边实验室有xilinx传统 
2. 前一代设计采用spantran-6（约5年前）
3. 设计成本压力不大
4. vivado不支持6系列及以下

* 综上考虑xilinx 7系列

-----------------------------------

1. 设计参考开发板：Cmod A7-35T Artix-7
2. 相对低成本及供货稳定性
3. 封装说得过去

* 综上考虑 XC7A35T系列，采购考虑FTG256成本最低

------------------------------

## 电源选型
1. 三电压等级供电：1V0 1V8 3V3
2. 上电时序从低到高，没有办法分级稳压
3. 上电冲击电流较大
4. 考虑板面积，发热量

* 综上
    - 最优选项为高频率三输出斩波
        + 评估板LTC3569成本较高
        + TI TPS65261 不易焊接
    - 暂采用三路带使能LDO，考虑使用RC延时上电电路

----------------------------

## IO 扇出
1. 对FPGA还没有很系统的认识，没有使用经验
2. 参考Cmod A7-35T的设计
3. 尽力兼容之前设计接口

* 综上
    - 争取所有IO就近扇出
    - 首先满足之前接口需求
    - 多余IO口就近扇出作为Pmod接口
    - 零散IO就近作为ITAC模块
    - 更零散IO不做处理，直接悬空

-------------------------------------------

1. FPGA短时间内为加速ip服务，并非高速io信号

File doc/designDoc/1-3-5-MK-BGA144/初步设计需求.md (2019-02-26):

~~bga 主控~~ 
~~小~~
~~多层~~
~~usb~~
~~电源管理~~
~~扩展存储 也用BGA~~
~~调试接口~~
~~成本低~~
~~外部总线~~
~~随机数~~
~~加密~~
~~可以考虑FRDM-K64~~

* 小型化方法
    - 插接金手指
    - 核心板
    - 贴片金手指
    - 塔式结构金手指
    - 单板 

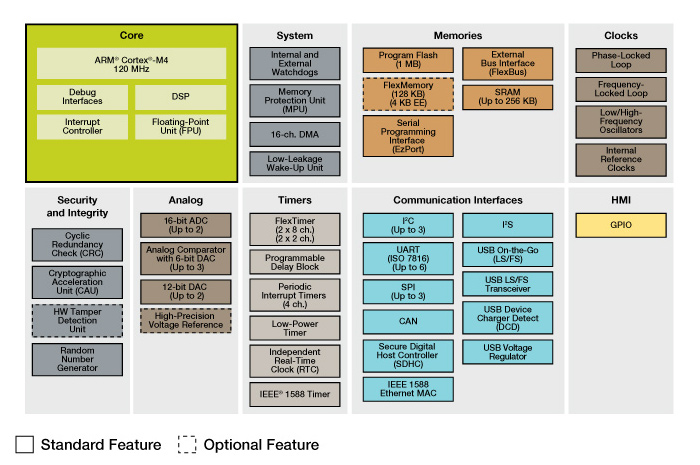
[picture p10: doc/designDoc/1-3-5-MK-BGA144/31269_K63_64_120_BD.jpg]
K64


* mbed支持
    - NXP
        + KL
            ~~* KL25~~
            ~~* KL46~~
            ~~* KL05~~
            ~~* KL27~~
            ~~* KL43~~
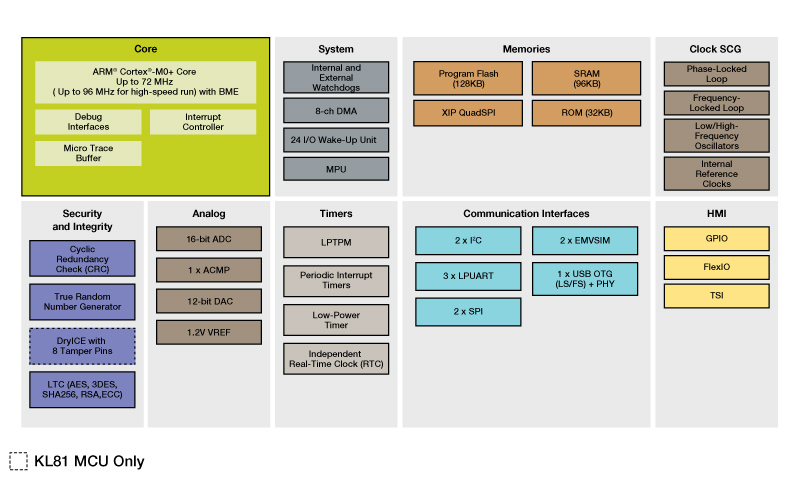
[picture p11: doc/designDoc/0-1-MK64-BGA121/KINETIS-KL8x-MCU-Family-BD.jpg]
KL82
            * KL82 
                - TRNG
                - AES SHA
                - USB
        + KK            
            ~~* K20~~
            ~~* K22~~
            * K64 

                - CAN
                - USB
                - SDHC
                - IEEE 1588
                - 随机数
                - crc cau
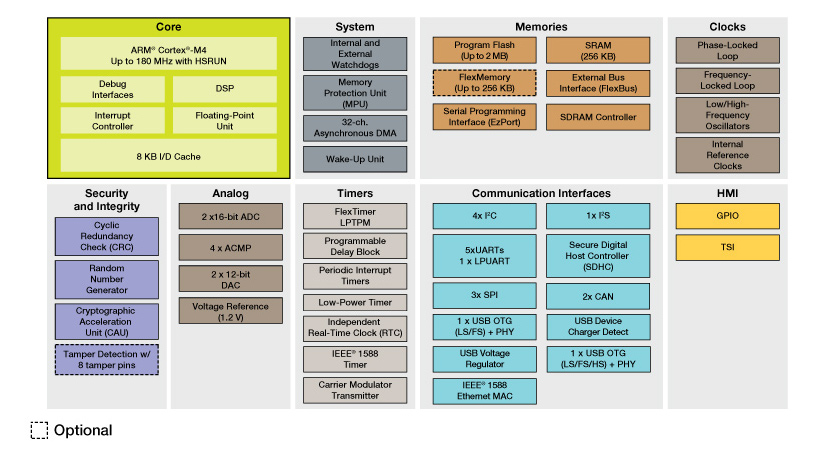
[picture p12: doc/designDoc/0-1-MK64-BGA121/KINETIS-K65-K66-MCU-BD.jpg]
K66
            * K66 
                - can
                - IEEE 1588
                - usb
                - SDHC
                - TRNG
                - CAU CRC
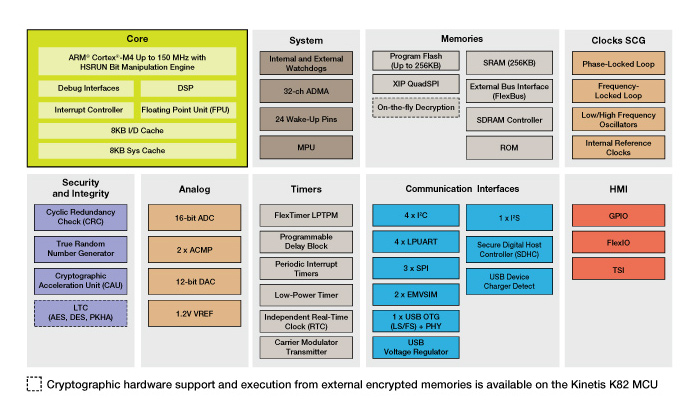
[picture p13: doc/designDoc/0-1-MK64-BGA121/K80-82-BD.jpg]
K82
            * K82F 
                - 面向安全，有加密和随机数
                - USB
                - 150MHZ
        + KW
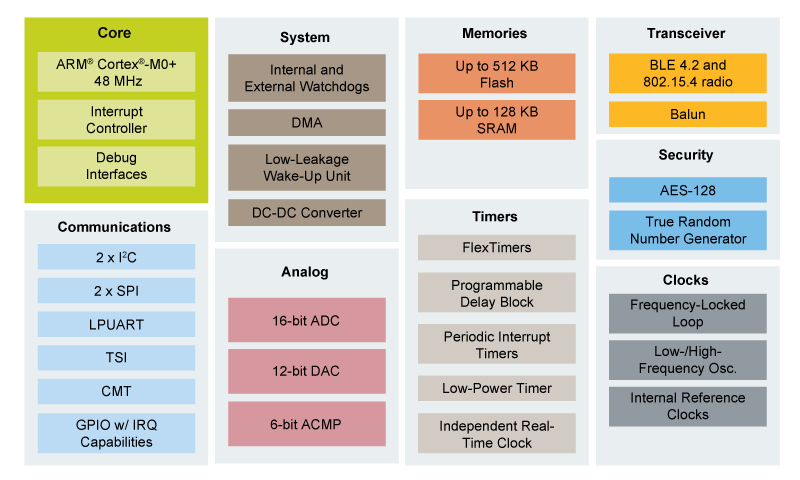
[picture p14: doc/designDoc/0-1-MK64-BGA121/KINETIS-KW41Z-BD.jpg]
KW41Z
            * KW41Z 
                - AES
                - TRNG
                - 15.4
                - BT
                - cortex-M0
    - ST
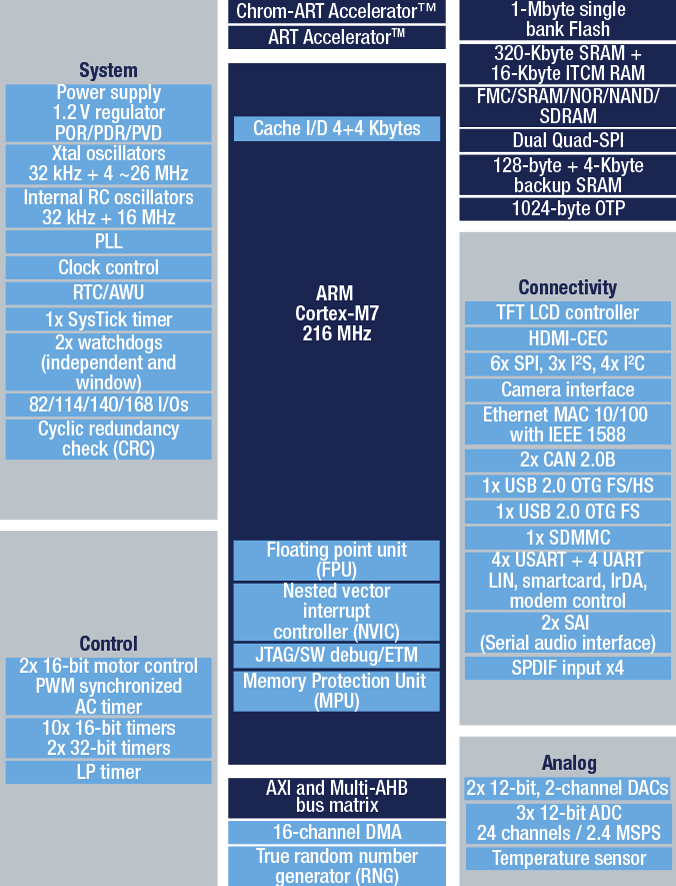
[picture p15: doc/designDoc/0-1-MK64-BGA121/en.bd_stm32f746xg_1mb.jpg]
STM32F7
        + STM32F7（好像是面向图像的） 
            * 有随机数发生器
            * CRC
            * can
            * usb
            * IEEE 1588v2 
            * HDMI
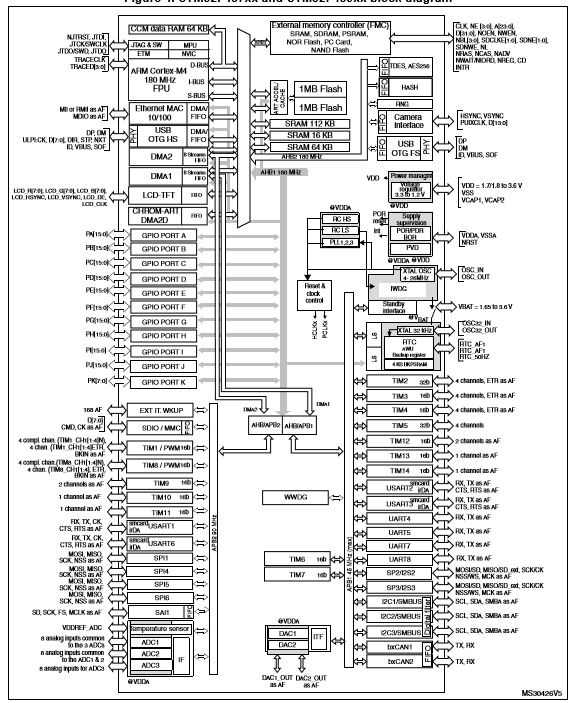
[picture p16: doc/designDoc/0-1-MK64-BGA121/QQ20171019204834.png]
stm32
        + STM32F439ZI (QFP144) 
            * USB
            * TRNG
            * AES
            * SDIO
            * ETHERENT
    - MAXIUM
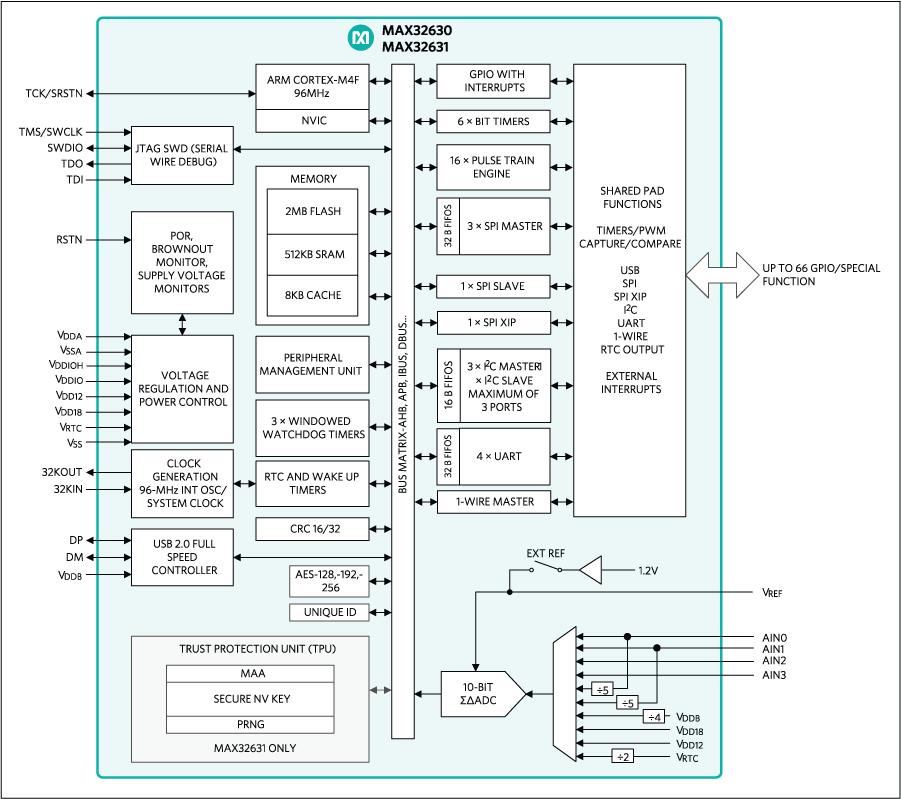
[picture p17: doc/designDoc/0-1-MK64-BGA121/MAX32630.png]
MAX32630
        + MAX32630FTHR 
            * USB
            * AES
            * PRNG
            * CRC
            * 96MHZ
[可视版本](https://github.com/whutddk/userpicture/blob/common-dev/初步设计需求.md)

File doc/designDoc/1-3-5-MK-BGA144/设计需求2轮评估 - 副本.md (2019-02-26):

# 通用平台第二轮评估

K64F
* MK64FN1M0VDC12
* MK64FN1M0VMD12 (已停产)
* MK64FX512VDC12
* MK64FX512VMD12
* 型号
    - FX（可以申请样品）
        + 512KBFLASH + 128KBFlexMem + 256KBSRAM + 4KBEEPROM 
    - FN
        + 1MBFLASH + 256KBSRAM 
* BGA封装
    - VDC
        + 80+IO + 121PIN + 8*8*0.5
    - VMD
        + 100IO + 144PIN + 13*13*1.46

---------------

# 主控定型：MK64FX512VDC(小容量，小封装，争取申请样品)

## 二级设计需求
* adrunio 接口可扩展
    - 提供板外供电
* openSDA下载口
    - ftl232 转usb
    - 不使用 K20二次JTAG
* 可二次画板扩展到ARM+FPGA结构
* 外扩RAM
    - 已定型
    - EM7164SU16（1M+16BIT）
    - 74LVC16373    
* RTC
* 额外USB接口，可大电流供电
* 4-6层板
    - 第一版设计应该只需要2层布线+2层电源，争取达到单面放置元器件

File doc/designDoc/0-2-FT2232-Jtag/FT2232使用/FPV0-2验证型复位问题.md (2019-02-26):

# FT2232 IO配置问题

>> ftdi_layout_init 0x0f18 0x0fff

* 16+16 IO配置只针对一个通道,高8位、低8位对应FT2232原理图上GPIOL/H(X),只针对MPSSE模式
* 前一组为output data，后一组为direction，1为output，0 为input。

>> ftdi_layout_signal nSRST -data 0x0001 -noe 0x0100

* 设置system reset 信号线为GPIOL0,其高阻控制线为GPIOL2
* 复位线需要具有高阻态功能，由于FT2232HL不提供三态输出，不进行配置将会报错。
* 三态复位线应该参考100ask-JTAGv3设计图纸

>> reset_config srst_only

* 配置系统复位

>> reset_config none

* 在复位线有问题时屏蔽复位

>> reset_config srst_only srst_push_pull

* 复杂配置如此叠加

>> ftdi_layout_signal LED1 -data 0x0800 -ninput 0x0001

* 将高第3位配置为LED1,数据来源于低0位数据反相（驱动能力问题测试没有通过）

# 20180309 
* 可以单线复位 L0-L3是高位不是低位，rst设置推挽可以不用OE

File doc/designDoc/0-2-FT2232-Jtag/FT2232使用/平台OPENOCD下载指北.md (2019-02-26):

# 通用平台V0.1型下载指北
## openocd

——————————————————————————————————————————————————————

### 新板子
* FT2232D的默认出厂VID和PID是 0x0403 0x6010，由于调试中驱动出现问题PID用FT_PROM改为0x6011
* portA功能设置为234FIFO
* portA驱动设置为D2XX
* 烧写EEPROM
* 设备名可以随意

----------------

### 统一设置
* 有可能需要先安装官方驱动
* zadig换驱动：将interface 0 的设备换为libusbK
* 一旦换驱动FT_PROM就无法识别FT2232了，就需要重装驱动
* openocd的interface文件可以使用我提供的文件 **ft2232D.cfg** ：

                >> interface ftdi

                >> #设置设备VID和PID要和设备设置一致
                >> #设备名可以缺省
                >> #FT2232D的通道号一定是0

                >> ftdi_vid_pid 0x0403 0x6011
                >> ftdi_channel 0

                >> #初始化IO,一定要初始化
                >> #设置复位IO，该版本并没有接复位线，但还需要假装接了
                >> ftdi_layout_init 0x0538 0x057b
                >> ftdi_layout_signal nSRST -data 0x0020 -noe 0x0100

* 之后下载基本参照之前的openocd的下载方式 : 

                >>(cmd openocd) openocd.exe -f ../scripts/board/frdm-k64.cfg 

* 需要指出 frdm-K64.cfg里的source [find interface/cmsis-dap.cfg]需要重新指向ft2232D.cfg : 

                >> (cmd gdb) arm-none-eabi-gdb.exe ./BUILD/K64F/GCC_ARM/mbed-os-example-blinky.elf
                >> (gdb) target remote localhost:3333

* 将mbed或者iar生成的bin文件放到OPENOCD文件夹下

* 由于没有接入复位线，需要手工复位
* 按住复位按钮，输入 : 

                >> (gdb) monitor program mbed-os-example-blinky.bin

* 回车之后释放复位按键即可下载
* 下载完成后再按一次复位启动

FT_PROM设置PID
FT_PROM设置设备名
FT_PROM设置portA硬件
FT_PROM设置portA驱动
FT_PROM设置portB硬件
FT_PROM设置portB驱动
FT_PROM烧写EEPROM
zadig换驱动
IAR生成BIN文件

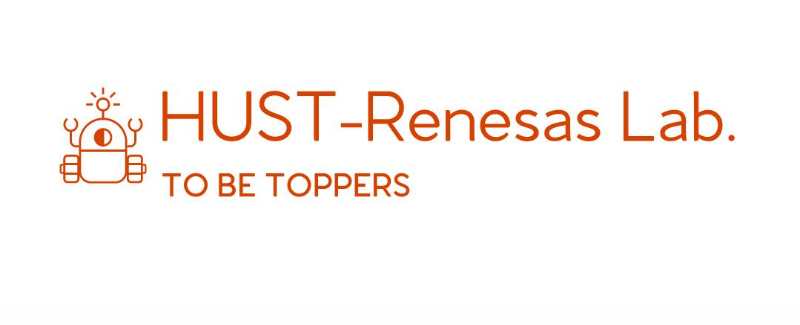
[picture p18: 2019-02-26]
doc/designDoc/1-1-MK-LQFP144/mmexport1516165831264.jpg

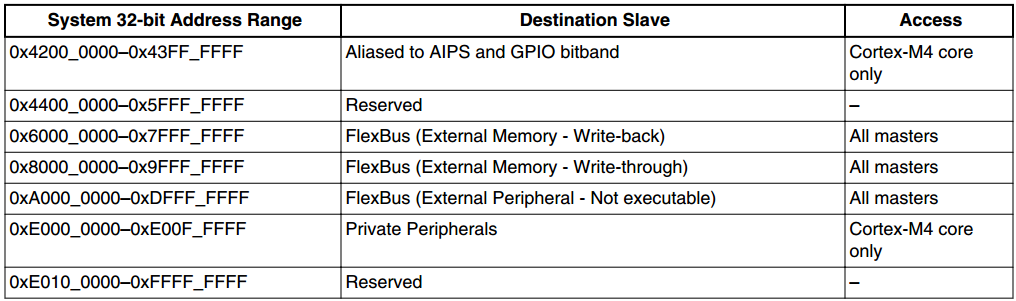
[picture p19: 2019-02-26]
doc/designDoc/1-3-5-MK-BGA144/QQ截图20171207112306.png

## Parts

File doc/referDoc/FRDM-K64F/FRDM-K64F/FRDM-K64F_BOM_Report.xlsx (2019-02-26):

 | Report Name | Freescale Costed BOM Report
 | Date Generated: | 09/06/2014 06:13 AM MST
 | Item Number: | FRDM-K64F
 | Item Revision: | MCO33692
 | BOM-Levels: | BOM-Levels: All Levels Item-Types: Part;CADPart;MarketingPN; Mfr-Part-Lifecycle-Phases: Active;ROHS Active; Mfr-Statuses: Alternate;Preferred;
Level | Item Type | Item Number | Item Rev | Description | Mfr. Name | Mfr. Part Number | Qty | Ref Des | Notes | Mfr Part Status | Mfr Preferred Status
0 | MarketingPN | FRDM-K64F | B MCO33692 | FRDM-K64F | GARTIN TECHNOLOGIES | FRDM-K64F |  |  |  | ROHS Active | Preferred
0 | MarketingPN | FRDM-K64F | B MCO33692 | FRDM-K64F | Shenzhen Embest Technology Co., Ltd | FRDM-K64F |  |  |  | Active | Preferred
.1 | Part | 975-28163 | B ECO49755 | HW PACKOUT, FRDM-K64F |  |  | 1
..2 | Part | 570-76099 | A MCO35005 | BOX, FREEDOM PLATFORM CUSTOM FOR K64F |  |  | 1
...3 | Part | 806-76099 | A MCO35228 | BOX ARTWORK, FREEDOM PLATFORM FOR K64F |  |  | 0
..2 | Part | 920-28163 | B ECO49856 | INSERT, COLOR PRINTED CARD, FRDM-K64F | HIBBERT GROUP | 920-27556 | 1 |  |  | Active | Preferred
..2 | Part | 805-75203 | H1 MCO35194 | LABEL, PDC BARCODE | International Paper | MOT-PDC (B1850101-7) | 1 |  |  | Active | Preferred
..2 | Part | 805-75203 | H1 MCO35194 | LABEL, PDC BARCODE | NORTEC INTERNATIONAL/AMI LTD. | K545-PAI | 1 |  |  | Active | Preferred
..2 | Part | 700-28163 | B MCO35000 | PWA, FRDM-K64F |  |  | 1
...3 | Part | 170-28163 | E MCO34911 | PWB, FRDM-K64F | BARE BOARD GROUP | 170-28163_A | 1 |  |  | ROHS Active | Preferred
...3 | Part | 170-28163 | E MCO34911 | PWB, FRDM-K64F | BARE BOARD GROUP | 170-28163_B | 1 |  |  | ROHS Active | Preferred
...3 | Part | 170-28163 | E MCO34911 | PWB, FRDM-K64F | BARE BOARD GROUP | 170-28163_B1 | 1 |  |  | ROHS Active | Preferred
...3 | Part | 170-28163 | E MCO34911 | PWB, FRDM-K64F | BARE BOARD GROUP | 170-28163_C | 1 |  |  | ROHS Active | Preferred
...3 | Part | 170-28163 | E MCO34911 | PWB, FRDM-K64F | BARE BOARD GROUP | 170-28163_D | 1 |  |  | ROHS Active | Preferred
...3 | Part | 170-28163 | E MCO34911 | PWB, FRDM-K64F | BARE BOARD GROUP | 170-28163_E | 1 |  |  | ROHS Active | Preferred
...3 | Part | 280-76746 | MCO34917 | BUMPON CYLINDRICAL .312X.215 BLK | SHENZHEN XINLANTIAN TE. CH .CO.LTD | 280-76746 | 4 |  |  | ROHS Active | Preferred
...3 | Part | 805-76618 | A MCO35096 | LABEL, 0.275"X0.275", ASSEMBLY / REVISION |  |  | 1
...3 | Part | 805-75481 | A MCO34929 | LABEL, 1" X 0.25" SERIAL NUMBER |  |  | 1
...3 | CADPart | 211-30048 | A MCO35547 | SHUNT -- 0.1IN SP JMPR -- AU BLACK | SAMTEC | SNT-100-BK-G | 2 |  | SEE ASY FILE FOR DETAIL | ROHS Active | Preferred
...3 | Part | 750-28163 | E MCO34918 | SUB ASSEMBLY, SCHEMATIC PARTS, 700-28163, FRDM-K64F |  |  | 1
....4 | CADPart | 150-30028 | A1 MCO34883 | CAP CER 1.0UF 16V 10% X7R 0603 | AVX | 0603YC105KAT2A | 1 | C28 |  | ROHS Active | Preferred
....4 | CADPart | 150-30028 | A1 MCO34883 | CAP CER 1.0UF 16V 10% X7R 0603 | CAL-CHIP | GMC10X7R105K16NT-LF | 1 | C28 |  | Active | Alternate
....4 | CADPart | 150-30028 | A1 MCO34883 | CAP CER 1.0UF 16V 10% X7R 0603 | CAPAX TECHNOLOGIES INC. | 0603X105K160-SN-T | 1 | C28 |  | ROHS Active | Alternate
....4 | CADPart | 150-30028 | A1 MCO34883 | CAP CER 1.0UF 16V 10% X7R 0603 | MURATA | GRM188R71C105KA12D | 1 | C28 |  | Active | Alternate
....4 | CADPart | 150-30028 | A1 MCO34883 | CAP CER 1.0UF 16V 10% X7R 0603 | YAGEO AMERICA | CC0603KRX7R7BB105 | 1 | C28 |  | ROHS Active | Alternate
....4 | CADPart | 150-75182 | A1 MCO34818 | CAP CER 0.1UF 16V 10% X7R 0402 | CAL-CHIP | GMC04X7R104K16NT-LF | 6 | C22,C24,C26,C39,C60,C61 |  | Active | Alternate
....4 | CADPart | 150-75182 | A1 MCO34818 | CAP CER 0.1UF 16V 10% X7R 0402 | KEMET | C0402C104K4RAC | 6 | C22,C24,C26,C39,C60,C61 |  | Active | Preferred
....4 | CADPart | 150-75182 | A1 MCO34818 | CAP CER 0.1UF 16V 10% X7R 0402 | MURATA | GRM155R71C104KA88D | 6 | C22,C24,C26,C39,C60,C61 |  | Active | Alternate
....4 | CADPart | 150-75182 | A1 MCO34818 | CAP CER 0.1UF 16V 10% X7R 0402 | SKYMOS | 0402B104K160NT | 6 | C22,C24,C26,C39,C60,C61 |  | Active | Alternate
....4 | CADPart | 150-75182 | A1 MCO34818 | CAP CER 0.1UF 16V 10% X7R 0402 | TDK | C1005X7R1C104KT | 6 | C22,C24,C26,C39,C60,C61 |  | ROHS Active | Alternate
....4 | CADPart | 150-75182 | A1 MCO34818 | CAP CER 0.1UF 16V 10% X7R 0402 | VENKEL COMPANY | C0402X7R160-104KNE | 6 | C22,C24,C26,C39,C60,C61 |  | ROHS Active | Alternate
....4 | CADPart | 150-75182 | A1 MCO34818 | CAP CER 0.1UF 16V 10% X7R 0402 | VENKEL COMPANY | C0402X7R160-104KNP | 6 | C22,C24,C26,C39,C60,C61 |  | ROHS Active | Alternate
....4 | CADPart | 150-75182 | A1 MCO34818 | CAP CER 0.1UF 16V 10% X7R 0402 | VENKEL COMPANY | C0402X7R160-104KSNE | 6 | C22,C24,C26,C39,C60,C61 |  | ROHS Active | Alternate
....4 | CADPart | 150-75182 | A1 MCO34818 | CAP CER 0.1UF 16V 10% X7R 0402 | WALSIN TECHNOLOGY CORP. | 0402B104K160CT | 6 | C22,C24,C26,C39,C60,C61 |  | ROHS Active | Alternate
....4 | CADPart | 150-75182 | A1 MCO34818 | CAP CER 0.1UF 16V 10% X7R 0402 | YAGEO AMERICA | CC0402KRX7R7BB104 | 6 | C22,C24,C26,C39,C60,C61 |  | Active | Alternate
....4 | CADPart | 150-75286 | A MCO34876 | CAP CER 100PF 50V 5% C0G 0603 | AVX | 06035A101JAT2A | 1 | C38 |  | ROHS Active | Preferred
....4 | CADPart | 150-75286 | A MCO34876 | CAP CER 100PF 50V 5% C0G 0603 | KEMET | C0603C101J5GAC | 1 | C38 |  | Active | Alternate
....4 | CADPart | 150-75286 | A MCO34876 | CAP CER 100PF 50V 5% C0G 0603 | MURATA | GRM1885C1H101JA01D | 1 | C38 |  | Active | Alternate
....4 | CADPart | 150-75286 | A MCO34876 | CAP CER 100PF 50V 5% C0G 0603 | VENKEL COMPANY | C0603C0G500-101JNE | 1 | C38 |  | ROHS Active | Alternate
....4 | CADPart | 150-75286 | A MCO34876 | CAP CER 100PF 50V 5% C0G 0603 | WALSIN TECHNOLOGY CORP. | 0603N101J500LT | 1 | C38 |  | ROHS Active | Alternate
....4 | CADPart | 150-75487 | A1 MCO34806 | CAP CER 4.7UF 6.3V 10% X5R 0603 | KEMET | C0603C475K9PACTU | 1 | C21 |  | Active | Alternate
....4 | CADPart | 150-75487 | A1 MCO34806 | CAP CER 4.7UF 6.3V 10% X5R 0603 | MURATA | GRM188R60J475KE19D | 1 | C21 |  | Active | Alternate
....4 | CADPart | 150-75487 | A1 MCO34806 | CAP CER 4.7UF 6.3V 10% X5R 0603 | VENKEL COMPANY | C0603X5R6R3-475KNP | 1 | C21 |  | Active | Preferred
....4 | CADPart | 150-75487 | A1 MCO34806 | CAP CER 4.7UF 6.3V 10% X5R 0603 | Yageo | CC0603KRX5R5BB475 | 1 | C21 |  | ROHS Active | Alternate
....4 | CADPart | 150-75634 | A1 MCO34861 | CAP CER 0.1UF 10V 10% X5R 0402 | AVX | 0402ZD104KAT2A | 22 | C3,C4,C7,C8,C10,C13,C14,C16,C18,C25,C27,C32,C37,C42,C43,C46,C47,C49,C55-C58 |  | ROHS Active | Alternate
....4 | CADPart | 150-75634 | A1 MCO34861 | CAP CER 0.1UF 10V 10% X5R 0402 | JOHANSON DIELECTRICS | 100R07X104KV4T | 22 | C3,C4,C7,C8,C10,C13,C14,C16,C18,C25,C27,C32,C37,C42,C43,C46,C47,C49,C55-C58 |  | ROHS Active | Alternate
....4 | CADPart | 150-75634 | A1 MCO34861 | CAP CER 0.1UF 10V 10% X5R 0402 | KEMET | C0402C104K8PAC | 22 | C3,C4,C7,C8,C10,C13,C14,C16,C18,C25,C27,C32,C37,C42,C43,C46,C47,C49,C55-C58 |  | ROHS Active | Preferred
....4 | CADPart | 150-75634 | A1 MCO34861 | CAP CER 0.1UF 10V 10% X5R 0402 | MURATA | GRM155R61A104KA01D | 22 | C3,C4,C7,C8,C10,C13,C14,C16,C18,C25,C27,C32,C37,C42,C43,C46,C47,C49,C55-C58 |  | ROHS Active | Alternate
....4 | CADPart | 150-75634 | A1 MCO34861 | CAP CER 0.1UF 10V 10% X5R 0402 | TDK | C1005X5R1A104KB | 22 | C3,C4,C7,C8,C10,C13,C14,C16,C18,C25,C27,C32,C37,C42,C43,C46,C47,C49,C55-C58 |  | Active | Alternate
....4 | CADPart | 150-75772 | A1 MCO34744 | CAP CER 1.0UF 10V 10% X5R 0402 | CAL-CHIP | GMC04X5R105K10NT-LF | 2 | C12,C45 |  | Active | Alternate
....4 | CADPart | 150-75772 | A1 MCO34744 | CAP CER 1.0UF 10V 10% X5R 0402 | MURATA | GRM155R61A105KE15D | 2 | C12,C45 |  | ROHS Active | Alternate
....4 | CADPart | 150-75772 | A1 MCO34744 | CAP CER 1.0UF 10V 10% X5R 0402 | WALSIN TECHNOLOGY CORP. | 0402X105K100CT | 2 | C12,C45 |  | Active | Alternate
....4 | CADPart | 150-75772 | A1 MCO34744 | CAP CER 1.0UF 10V 10% X5R 0402 | YAGEO AMERICA | CC0402KRX5R6BB105 | 2 | C12,C45 |  | ROHS Active | Preferred
....4 | CADPart | 150-76334 | A MCO34876 | CAP CER 1000PF 50V 5% C0G 0402 | MURATA | GRM1555C1H102JA01D | 1 | C2 |  | Active | Preferred
....4 | CADPart | 150-76334 | A MCO34876 | CAP CER 1000PF 50V 5% C0G 0402 | WALSIN TECHNOLOGY CORP. | 0402N102J500LT | 1 | C2 |  | Active | Alternate
....4 | CADPart | 150-77680 | A MCO34891 | CAP CER 24PF 50V 5% C0G 0402 | MURATA | GRM1555C1H240JA01D | 2 | C29,C35 |  | ROHS Active | Preferred
....4 | CADPart | 150-77832 | A1 MCO34806 | CAP CER 10UF 6.3V 10% X5R 0603 | CAL-CHIP | GMC10X5R106K6R3NT-LF | 1 | C34 |  | ROHS Active | Alternate
....4 | CADPart | 150-77832 | A1 MCO34806 | CAP CER 10UF 6.3V 10% X5R 0603 | TDK | C1608X5R0J106KT | 1 | C34 |  | ROHS Active | Preferred
....4 | CADPart | 150-78463 | A1 MCO34829 | CAP CER 4.7UF 6.3V 20% X5R 0402 | TDK | C1005X5R0J475M | 2 | C17,C23 |  | Active | Alternate
....4 | CADPart | 150-78463 | A1 MCO34829 | CAP CER 4.7UF 6.3V 20% X5R 0402 | VENKEL COMPANY | C0402X5R6R3-475MNP | 2 | C17,C23 |  | Active | Preferred
....4 | CADPart | 150-78564 | A MCO34647 | CAP CER 2.2uF 10V 10% X7R 0603 | MURATA | GRM188R71A225KE15D | 2 | C11,C40 |  | ROHS Active | Alternate
....4 | CADPart | 150-78564 | A MCO34647 | CAP CER 2.2uF 10V 10% X7R 0603 | SMEC | MCCB225K1NRTF | 2 | C11,C40 |  | ROHS Active | Alternate
....4 | CADPart | 150-78564 | A MCO34647 | CAP CER 2.2uF 10V 10% X7R 0603 | TAIYO YUDEN | LMK107B7225KA-T | 2 | C11,C40 |  | Active | Preferred
....4 | CADPart | 150-78564 | A MCO34647 | CAP CER 2.2uF 10V 10% X7R 0603 | Yageo | CC0603KRX7R6BB225 | 2 | C11,C40 |  | Active | Alternate
....4 | CADPart | 150-78609 | A MCO34806 | CAP CER 10UF 10V 20% X5R 0603 | TAIYO YUDEN | LMK107BJ106MALTD | 1 | C51 |  | Active | Preferred
....4 | CADPart | 150-78609 | A MCO34806 | CAP CER 10UF 10V 20% X5R 0603 | TDK | C1608X5R1A106M | 1 | C51 |  | ROHS Active | Alternate
....4 | CADPart | 150-78609 | A MCO34806 | CAP CER 10UF 10V 20% X5R 0603 | VENKEL COMPANY | C0603X5R100-106MNP | 1 | C51 |  | ROHS Active | Alternate
....4 | CADPart | 150-78974 | A MCO34820 | CAP CER 2.2uF 10V 10% X5R 0402 | TDK | C1005X5R1A225K | 1 | C59 |  | Active | Preferred
....4 | CADPart | 150-78976 | A MCO34858 | CAP CER 4.7uF 16V 10% X5R 0603 | TDK | C1608X5R1C475K | 1 | C5 |  | Active | Preferred
....4 | CADPart | 150-79092 | A MCO34818 | CAP CER 10uF 16V 20% X5R 0603 | TAIYO YUDEN | EMK107BBJ106MA-T | 2 | C15,C41 |  | Active | Preferred
....4 | CADPart | 150-79092 | A MCO34818 | CAP CER 10uF 16V 20% X5R 0603 | TDK | C1608X5R1C106M080AB | 2 | C15,C41 |  | Active | Alternate
....4 | CADPart | 150-79255 | A MCO34840 | CAP CER 10uF 10V 20% X5R 0402 | SAMSUNG | CL05A106MP5NUNC | 1 | C1 |  | Active | Preferred
....4 | CADPart | 180-78156 | A MCO34856 | IND FER BEAD 330OHM@100MHZ 1.7A 0603 | TDK | MPZ1608S331A | 4 | L1,L2,L4,L5 |  | Active | Preferred
....4 | CADPart | 210-75442 | A1 MCO34818 | HDR 1X3 TH 100MIL SP 330H AU 98L | 3M | 929647-01-03-EU | 1 | J25 |  | ROHS Active | Alternate
....4 | CADPart | 210-75442 | A1 MCO34818 | HDR 1X3 TH 100MIL SP 330H AU 98L | ANYTRONIC CORPORATION LIMITED | 090021S03018-2LF | 1 | J25 |  | ROHS Active | Alternate
....4 | CADPart | 210-75442 | A1 MCO34818 | HDR 1X3 TH 100MIL SP 330H AU 98L | FRAMATOME CONNECTORS INTERNATIONAL | 69190-603H | 1 | J25 |  | Active | Alternate
....4 | CADPart | 210-75442 | A1 MCO34818 | HDR 1X3 TH 100MIL SP 330H AU 98L | SAMTEC | HTSW-103-07-S-S | 1 | J25 |  | Active | Preferred
....4 | CADPart | 210-76752 | A MCO34818 | HDR 1X2 TH 100MIL SP 330H SN 115L | SAMTEC | TSW-102-23-T-S | 2 | J14,J21 |  | ROHS Active | Preferred
....4 | CADPart | 210-80192 | A MCO34866 | HDR 2X5 TH 50MIL CTR 167H AU 91L | ANYTRONIC CORPORATION LIMITED | 0922S0205011N6T-2LF | 2 | J9,J10 |  | Active | Preferred
....4 | CADPart | 210-80192 | A MCO34866 | HDR 2X5 TH 50MIL CTR 167H AU 91L | SULLINS ELECTRONICS CORP | GRPB052VWVN-RC | 2 | J9,J10 |  | Active | Alternate
....4 | CADPart | 210-80460 | A MCO34845 | CON 8 RJ RA TH 2.54MM SP 580H AU 132L | UDE CORP | RB1-125BAG1A | 1 | J13 |  | Active | Preferred
....4 | CADPart | 210-80536 | A MCO34878 | CON 2X6 SKT TH 100MIL CTR 540H SN 190L | SAMTEC | ESQ-106-23-T-D | 1 | J4 |  | Active | Preferred
....4 | CADPart | 210-80537 | A MCO34884 | CON 2X10 SKT TH 100MIL CTR 540H SN 190L | SAMTEC | ESQ-110-23-T-D | 1 | J2 |  | Active | Preferred
....4 | CADPart | 210-80538 | A MCO34878 | CON 2X8 SKT TH 100MIL CTR 545H SN 190L | SAMTEC | ESQ-108-23-T-D | 2 | J1,J3 |  | Active | Preferred
....4 | CADPart | 211-76642 | A MCO34880 | TEST POINT PAD 30MIL DIA SMT, NO PART TO ORDER |  |  | 16 | TP1-TP15,TP17
....4 | CADPart | 211-78722 | A MCO34890 | CON 1X5 USB_MICRO_AB_RECEPTACLE RA SMT 0.65MM SP 105H AU | MOLEX | 47589-0001 | 2 | J22,J26 |  | ROHS Active | Preferred
....4 | CADPart | 211-79395 | A MCO34900 | CON 8 SD CARD PUSH SMT 1.1MM SP 75H AU | MOLEX | 1050270001 | 1 | J15 |  | Active | Preferred
....4 | CADPart | 230-77653 | A MCO34905 | XTAL 32.768KHZ 12.5PF 20PPM 3.2X1.5MM SMT | ABRACON CORPORATION | ABS07-32.768KHZ-T | 1 | Y3 |  | Active | Preferred
....4 | CADPart | 230-77653 | A MCO34905 | XTAL 32.768KHZ 12.5PF 20PPM 3.2X1.5MM SMT | ECS INC. INTERNATIONAL | ECS-.327-12.5-34B | 1 | Y3 |  | ROHS Active | Alternate
....4 | CADPart | 230-77664 | A1 MCO34890 | XTAL 8.00MHZ RSN CERAMIC -- SMT | MURATA | CSTCE8M00G55-R0 | 1 | Y1 |  | ROHS Active | Preferred
....4 | CADPart | 230-77979 | A MCO34887 | XTAL 25MHZ 18PF -- SMT | CTS | 403I35D25M00000 | 1 | Y2 |  | Active | Preferred
....4 | CADPart | 312-80039 | A MCO34818 | IC VREG LDO 1A 3.3V SOT223 | ON SEMICONDUCTOR | NCP1117ST33T3G | 1 | U17 |  | Active | Preferred
....4 | CADPart | 312-80418 | A MCO34818 | IC ACCELEROMETER AND MAGNETOMETER SENSOR 3-AXIS 2.5V QFN16 | FREESCALE SEMICONDUCTOR | FXOS8700CQ | 1 | U8 |  | ROHS Active | Preferred
....4 | CADPart | 312-80758 | A MCO34818 | IC XCVR 1BIT 3-STATE DUAL 1.2-5.5V XSON6 | NXP SEMICONDUCTORS | 74LVCH1T45GM,132 | 3 | U2,U7,U12 |  | Active | Preferred
....4 | CADPart | 312-80762 | A MCO34818 | IC XCVR DUAL SUPPLY 1.2 -5.5V XQFN8 | NXP SEMICONDUCTORS | 74LVC2T45GM,125 | 1 | U10 |  | Active | Preferred
....4 | CADPart | 312-80763 | A MCO34818 | IC DUAL SUPPLY XCVR 50 MBPS 5.5V XQFN8 | NXP SEMICONDUCTORS | NTSX2102GU8H | 1 | U3 |  | Active | Preferred
....4 | CADPart | 312-80840 | A MCO34818 | IC XCVR 10/100M EPHY 3.3V QFN24 | MICREL | KSZ8081RNACA | 1 | U13 |  | Active | Preferred
....4 | CADPart | 315-78830 | A MCO34838 | IC INV DUAL SCHMITT TRIGGER 1.65-5.5V ULLGA6 | ON SEMICONDUCTOR | NLX2G14AMX1TCG | 1 | U9 |  | ROHS Active | Preferred
....4 | CADPart | 315-79199 | A1 MCO34818 | IC LIN SW PWR 0.8A 2.5-5.5V SOT23-6 | MICREL | MIC2005-0.8YM6 | 1 | U11 |  | Active | Preferred
....4 | CADPart | 344-01231 | B CO0094079 | IC MCU FLASH 128KB 50MHZ 1.71-3.6V QFN32 | FREESCALE SEMICONDUCTOR | MK20DX128VFM5 | 1 | U5 |  | Active | Preferred
....4 | CADPart | 344-01231 | B CO0094079 | IC MCU FLASH 128KB 50MHZ 1.71-3.6V QFN32 | FREESCALE SEMICONDUCTOR | PK20DX128VFM5 | 1 | U5 |  | ROHS Active | Alternate
....4 | CADPart | 344-02013 | A MCO34901 | IC MCU 1MB FLASH 120MHZ 1.71-3.6V LQFP100 | FREESCALE SEMICONDUCTOR | MK64FN1M0VLL12 | 1 | U14 |  | Active | Preferred
....4 | CADPart | 370-75079 | A1 MCO34818 | LED ULTRA BRIGHT RED SGL 30MA 0603 | LITE ON | LTST-C190KRKT | 1 | D1 |  | ROHS Active | Preferred
....4 | CADPart | 370-76565 | A MCO34818 | LED GRN SGL 20MA 0603 | OSRAM | LG L29K-G2J1-24-Z | 1 | D2 |  | ROHS Active | Preferred
....4 | CADPart | 370-76567 | A MCO34818 | LED RED BL GRN SGL 50/25/25mA SMT | Cree, Inc | CLV1A-FKB-CJ1M1F1BB7R4S3 | 1 | D12 |  | ROHS Active | Preferred
....4 | CADPart | 470-30297 | A MCO34818 | RES MF 220 OHM 1/10W 5% 0603 | KOA SPEER | RK73B1JTTD221J | 1 | R17 |  | ROHS Active | Preferred
....4 | CADPart | 470-30297 | A MCO34818 | RES MF 220 OHM 1/10W 5% 0603 | WALSIN TECHNOLOGY CORP. | WR06X221 JTL | 1 | R17 |  | Active | Alternate
....4 | CADPart | 470-30297 | A MCO34818 | RES MF 220 OHM 1/10W 5% 0603 | YAGEO AMERICA | RC0603JR-07220RL | 1 | R17 |  | ROHS Active | Alternate
....4 | CADPart | 470-30328 | A MCO34818 | RES MF 100 OHM 1/32W 5% 0402 | PANASONIC | ERAW33J101X | 2 | R36,R76 |  | ROHS Active | Preferred
....4 | CADPart | 470-30332 | A1 MCO34818 | RES MF 270 OHM 1/16W 5% 0402 | VISHAY INTERTECHNOLOGY | CRCW0402270RJNED | 2 | R71,R73 |  | ROHS Active | Preferred
....4 | CADPart | 470-30515 | A1 MCO34818 | RES MF 130 OHM 1/16W 1% 0402 | THYE MING TECH CO LTD | CR02FL6--130R | 1 | R88 |  | ROHS Active | Alternate
....4 | CADPart | 470-30515 | A1 MCO34818 | RES MF 130 OHM 1/16W 1% 0402 | VISHAY INTERTECHNOLOGY | CRCW0402130RFKED | 1 | R88 |  | ROHS Active | Preferred
....4 | CADPart | 470-30515 | A1 MCO34818 | RES MF 130 OHM 1/16W 1% 0402 | YAGEO AMERICA | RC0402FR-07130RL | 1 | R88 |  | ROHS Active | Alternate
....4 | CADPart | 470-30813 | A MCO34818 | RES MF 576 OHM 1/16W 1% 0402 | KOA SPEER | RK73H1ETTP5760F | 1 | R68 |  | ROHS Active | Preferred
....4 | CADPart | 470-30965 | A MCO34818 | RES MF 15K 1/16W 1% 0402 | KOA SPEER | RK73H1ETTP1502F | 1 | R30 |  | ROHS Active | Preferred
....4 | CADPart | 470-30965 | A MCO34818 | RES MF 15K 1/16W 1% 0402 | WALSIN TECHNOLOGY CORP. | WR04X1502FTL | 1 | R30 |  | ROHS Active | Alternate
....4 | CADPart | 470-31088 | A MCO34818 | RES MF 180K 1/16W 1% 0402 | KOA SPEER | RK73H1ETTP1803F | 1 | R11 |  | ROHS Active | Preferred
....4 | CADPart | 470-75394 | A1 MCO34818 | RES MF ZERO OHM 1/16W 5% 0402 | BOURNS | CR0402-J/-000GLF | 14 | R19,R24,R25,R28,R33,R38,R42,R45,R54,R60,R62,R63,R74,R80 |  | ROHS Active | Alternate
....4 | CADPart | 470-75394 | A1 MCO34818 | RES MF ZERO OHM 1/16W 5% 0402 | KOA SPEER | RK73Z1ETTP | 14 | R19,R24,R25,R28,R33,R38,R42,R45,R54,R60,R62,R63,R74,R80 |  | ROHS Active | Alternate
....4 | CADPart | 470-75394 | A1 MCO34818 | RES MF ZERO OHM 1/16W 5% 0402 | PANASONIC | ERJ2GE0R00X | 14 | R19,R24,R25,R28,R33,R38,R42,R45,R54,R60,R62,R63,R74,R80 |  | ROHS Active | Alternate
....4 | CADPart | 470-75394 | A1 MCO34818 | RES MF ZERO OHM 1/16W 5% 0402 | ROHM | MCR01MZPJ000 | 14 | R19,R24,R25,R28,R33,R38,R42,R45,R54,R60,R62,R63,R74,R80 |  | ROHS Active | Preferred
....4 | CADPart | 470-75394 | A1 MCO34818 | RES MF ZERO OHM 1/16W 5% 0402 | SEI ELECTRONICS INC | RMCF1/16S0.005%R | 14 | R19,R24,R25,R28,R33,R38,R42,R45,R54,R60,R62,R63,R74,R80 |  | ROHS Active | Alternate
....4 | CADPart | 470-75394 | A1 MCO34818 | RES MF ZERO OHM 1/16W 5% 0402 | SKYMOS | RC-0402-0000T | 14 | R19,R24,R25,R28,R33,R38,R42,R45,R54,R60,R62,R63,R74,R80 |  | ROHS Active | Alternate
....4 | CADPart | 470-75394 | A1 MCO34818 | RES MF ZERO OHM 1/16W 5% 0402 | SMEC | RC73JP2ZF | 14 | R19,R24,R25,R28,R33,R38,R42,R45,R54,R60,R62,R63,R74,R80 |  | ROHS Active | Alternate
....4 | CADPart | 470-75394 | A1 MCO34818 | RES MF ZERO OHM 1/16W 5% 0402 | THYE MING TECH CO LTD | CR-02JL6----0R | 14 | R19,R24,R25,R28,R33,R38,R42,R45,R54,R60,R62,R63,R74,R80 |  | ROHS Active | Alternate
....4 | CADPart | 470-75394 | A1 MCO34818 | RES MF ZERO OHM 1/16W 5% 0402 | VENKEL COMPANY | CR0402-16W-000T | 14 | R19,R24,R25,R28,R33,R38,R42,R45,R54,R60,R62,R63,R74,R80 |  | ROHS Active | Alternate
....4 | CADPart | 470-75394 | A1 MCO34818 | RES MF ZERO OHM 1/16W 5% 0402 | WALSIN TECHNOLOGY CORP. | WR04X000_PTL | 14 | R19,R24,R25,R28,R33,R38,R42,R45,R54,R60,R62,R63,R74,R80 |  | ROHS Active | Alternate
....4 | CADPart | 470-75394 | A1 MCO34818 | RES MF ZERO OHM 1/16W 5% 0402 | YAGEO AMERICA | RC0402JR-070RL | 14 | R19,R24,R25,R28,R33,R38,R42,R45,R54,R60,R62,R63,R74,R80 |  | ROHS Active | Alternate
....4 | CADPart | 470-75414 | A MCO34806 | RES MF 4.7K 1/10W 5% 0603 | BOURNS | CR0603-JW-472ELF | 2 | R9,R15 |  | ROHS Active | Alternate
....4 | CADPart | 470-75414 | A MCO34806 | RES MF 4.7K 1/10W 5% 0603 | KOA SPEER | RK73B1JTTD472J | 2 | R9,R15 |  | ROHS Active | Alternate
....4 | CADPart | 470-75414 | A MCO34806 | RES MF 4.7K 1/10W 5% 0603 | LIKET CORPORATION | 0603472J | 2 | R9,R15 |  | ROHS Active | Alternate
....4 | CADPart | 470-75414 | A MCO34806 | RES MF 4.7K 1/10W 5% 0603 | PANASONIC | ERJ3GEYJ472V | 2 | R9,R15 |  | ROHS Active | Alternate
....4 | CADPart | 470-75414 | A MCO34806 | RES MF 4.7K 1/10W 5% 0603 | SKYMOS | RC-0603-472JT | 2 | R9,R15 |  | ROHS Active | Alternate
....4 | CADPart | 470-75414 | A MCO34806 | RES MF 4.7K 1/10W 5% 0603 | VENKEL COMPANY | CR0603-10W-472JSNT | 2 | R9,R15 |  | ROHS Active | Alternate
....4 | CADPart | 470-75414 | A MCO34806 | RES MF 4.7K 1/10W 5% 0603 | VENKEL COMPANY | CR0603-10W-472JT | 2 | R9,R15 |  | ROHS Active | Alternate
....4 | CADPart | 470-75414 | A MCO34806 | RES MF 4.7K 1/10W 5% 0603 | VISHAY INTERTECHNOLOGY | CRCW06034K70JNEA | 2 | R9,R15 |  | ROHS Active | Preferred
....4 | CADPart | 470-75414 | A MCO34806 | RES MF 4.7K 1/10W 5% 0603 | WALSIN TECHNOLOGY CORP. | WR06X472JTL | 2 | R9,R15 |  | ROHS Active | Alternate
....4 | CADPart | 470-75414 | A MCO34806 | RES MF 4.7K 1/10W 5% 0603 | YAGEO AMERICA | RC0603JR-074K7L | 2 | R9,R15 |  | ROHS Active | Alternate
....4 | CADPart | 470-75416 | B MCO34818 | RES MF 10.0K 1/16W 1% AEC-Q200 0402 | KOA SPEER | RK73H1ETTP1002F | 12 | R6,R13,R14,R16,R21,R26,R27,R32,R35,R39,R43,R50 |  | ROHS Active | Alternate
....4 | CADPart | 470-75416 | B MCO34818 | RES MF 10.0K 1/16W 1% AEC-Q200 0402 | KOA SPEER | RK73H1ETTPL1002F | 12 | R6,R13,R14,R16,R21,R26,R27,R32,R35,R39,R43,R50 |  | Active | Alternate
....4 | CADPart | 470-75416 | B MCO34818 | RES MF 10.0K 1/16W 1% AEC-Q200 0402 | VIKING COMPONENTS | CR-02FL6---10K | 12 | R6,R13,R14,R16,R21,R26,R27,R32,R35,R39,R43,R50 |  | ROHS Active | Alternate
....4 | CADPart | 470-75416 | B MCO34818 | RES MF 10.0K 1/16W 1% AEC-Q200 0402 | VISHAY INTERTECHNOLOGY | CRCW040210K0FKED | 12 | R6,R13,R14,R16,R21,R26,R27,R32,R35,R39,R43,R50 |  | ROHS Active | Preferred
....4 | CADPart | 470-75591 | A MCO34818 | RES MF 100 OHM 1/16W 5% 0402 | BOURNS | CR0402-JW-101GLF | 1 | R2 |  | ROHS Active | Alternate
....4 | CADPart | 470-75591 | A MCO34818 | RES MF 100 OHM 1/16W 5% 0402 | PANASONIC | ERJ2GEJ101X | 1 | R2 |  | ROHS Active | Alternate
....4 | CADPart | 470-75591 | A MCO34818 | RES MF 100 OHM 1/16W 5% 0402 | SMEC | RC73L2Z101JTF | 1 | R2 |  | ROHS Active | Alternate
....4 | CADPart | 470-75591 | A MCO34818 | RES MF 100 OHM 1/16W 5% 0402 | VENKEL COMPANY | CR040216W101JT | 1 | R2 |  | ROHS Active | Preferred
....4 | CADPart | 470-75591 | A MCO34818 | RES MF 100 OHM 1/16W 5% 0402 | YAGEO AMERICA | RC0402JR-07100RL | 1 | R2 |  | ROHS Active | Alternate
....4 | CADPart | 470-75626 | A MCO34818 | RES MF 4.7K 1/16W 5% 0402 | BOURNS | CR0402-JW-472GLF | 5 | R4,R5,R12,R23,R37 |  | ROHS Active | Alternate
....4 | CADPart | 470-75626 | A MCO34818 | RES MF 4.7K 1/16W 5% 0402 | KOA SPEER | RK73B1ETTP472J | 5 | R4,R5,R12,R23,R37 |  | ROHS Active | Alternate
....4 | CADPart | 470-75626 | A MCO34818 | RES MF 4.7K 1/16W 5% 0402 | PANASONIC | ERJ2GEJ472X | 5 | R4,R5,R12,R23,R37 |  | ROHS Active | Alternate
....4 | CADPart | 470-75626 | A MCO34818 | RES MF 4.7K 1/16W 5% 0402 | SMEC | RC73L2Z472JTF | 5 | R4,R5,R12,R23,R37 |  | ROHS Active | Alternate
....4 | CADPart | 470-75626 | A MCO34818 | RES MF 4.7K 1/16W 5% 0402 | VENKEL COMPANY | CR040216W472JT | 5 | R4,R5,R12,R23,R37 |  | ROHS Active | Alternate
....4 | CADPart | 470-75626 | A MCO34818 | RES MF 4.7K 1/16W 5% 0402 | VISHAY INTERTECHNOLOGY | CRCW04024K70JNED | 5 | R4,R5,R12,R23,R37 |  | ROHS Active | Alternate
....4 | CADPart | 470-75626 | A MCO34818 | RES MF 4.7K 1/16W 5% 0402 | WALSIN TECHNOLOGY CORP. | WR04X472 JTL | 5 | R4,R5,R12,R23,R37 |  | ROHS Active | Alternate
....4 | CADPart | 470-75626 | A MCO34818 | RES MF 4.7K 1/16W 5% 0402 | YAGEO AMERICA | RC0402JR-074K7L | 5 | R4,R5,R12,R23,R37 |  | ROHS Active | Preferred
....4 | CADPart | 470-75790 | A1 MCO34818 | RES MF 33.0 OHM 1/16W 1% 0402 | BOURNS | CR0402FX33R0GLF | 4 | R20,R22,R57,R79 |  | ROHS Active | Alternate
....4 | CADPart | 470-75790 | A1 MCO34818 | RES MF 33.0 OHM 1/16W 1% 0402 | THYE MING TECH CO LTD | CR-02FL6---33R | 4 | R20,R22,R57,R79 |  | ROHS Active | Preferred
....4 | CADPart | 470-75790 | A1 MCO34818 | RES MF 33.0 OHM 1/16W 1% 0402 | WALSIN TECHNOLOGY CORP. | WR04X33R0FTL | 4 | R20,R22,R57,R79 |  | ROHS Active | Alternate
....4 | CADPart | 470-75790 | A1 MCO34818 | RES MF 33.0 OHM 1/16W 1% 0402 | YAGEO AMERICA | RC0402FR-0733RL | 4 | R20,R22,R57,R79 |  | Active | Alternate
....4 | CADPart | 470-75848 | A MCO34818 | RES MF 33 OHM 1/10W 5% 0603 | BOURNS | CR0603-JW-330ELF | 2 | R46,R49 |  | Active | Alternate
....4 | CADPart | 470-75848 | A MCO34818 | RES MF 33 OHM 1/10W 5% 0603 | KOA SPEER | RK73B1JTTD330J | 2 | R46,R49 |  | ROHS Active | Alternate
....4 | CADPart | 470-75848 | A MCO34818 | RES MF 33 OHM 1/10W 5% 0603 | PANASONIC | ERJ3GEYJ330V | 2 | R46,R49 |  | ROHS Active | Alternate
....4 | CADPart | 470-75848 | A MCO34818 | RES MF 33 OHM 1/10W 5% 0603 | VENKEL COMPANY | CR0603-10W-330JT | 2 | R46,R49 |  | ROHS Active | Alternate
....4 | CADPart | 470-75848 | A MCO34818 | RES MF 33 OHM 1/10W 5% 0603 | VISHAY INTERTECHNOLOGY | CRCW060333R0JNEA | 2 | R46,R49 |  | ROHS Active | Preferred
....4 | CADPart | 470-75848 | A MCO34818 | RES MF 33 OHM 1/10W 5% 0603 | WALSIN TECHNOLOGY CORP. | WR06X330JTL | 2 | R46,R49 |  | ROHS Active | Alternate
....4 | CADPart | 470-76037 | A1 MCO34818 | RES MF 1.0K 1/16W 1% 0402 | BOURNS | CR0402-FX-1001GLF | 1 | R29 |  | Active | Alternate
....4 | CADPart | 470-76037 | A1 MCO34818 | RES MF 1.0K 1/16W 1% 0402 | THYE MING TECH CO LTD | CR-02FL6----1K | 1 | R29 |  | ROHS Active | Alternate
....4 | CADPart | 470-76037 | A1 MCO34818 | RES MF 1.0K 1/16W 1% 0402 | WALSIN TECHNOLOGY CORP. | WR04X1001FTL | 1 | R29 |  | ROHS Active | Alternate
....4 | CADPart | 470-76037 | A1 MCO34818 | RES MF 1.0K 1/16W 1% 0402 | YAGEO AMERICA | RC0402FR-071KL | 1 | R29 |  | ROHS Active | Preferred
....4 | CADPart | 470-78028 | A MCO34818 | RES MF 6.49K 1/10W 1% 0603 | KOA SPEER | RK73H1JTTD6491F | 1 | R58 |  | ROHS Active | Preferred
....4 | CADPart | 470-80018 | A MCO34818 | ZERO OHM CUT TRACE 0603 PADS; NO PART TO ORDER |  |  | 1 | SH1
....4 | CADPart | 470-80689 | A MCO34818 | RNET ISO 4 33 OHM 1/16W 5% 0603 | PANASONIC | EXB-38V330JV | 1 | RN1 |  | Active | Preferred
....4 | CADPart | 480-76179 | A1 MCO34818 | DIODE TVS BIDIR -- 30V 0402 | BUSSMANN | 0402ESDA-MLP8 | 6 | U1,U4,U6,U15,U16,U18 |  | Active | Alternate
....4 | CADPart | 480-76179 | A1 MCO34818 | DIODE TVS BIDIR -- 30V 0402 | COOPER BUSSMANN | 0402ESDA-MLP1 | 6 | U1,U4,U6,U15,U16,U18 |  | Active | Preferred
....4 | CADPart | 480-78285 | A MCO34818 | DIODE SCH 1A 30V PowerDI123 | DIODES INC | DFLS130L-7 | 7 | D5-D11 |  | ROHS Active | Preferred
....4 | CADPart | 480-78582 | A MCO34818 | DIODE SCH 200MA 30V SOT323 | ON SEMICONDUCTOR | BAT54AWT1G | 1 | D3 |  | Active | Preferred
....4 | CADPart | 510-76958 | A MCO34818 | SW SPST MOM NO TACT 12V 50MA SMT | E SWITCH | TL1015BF160QG | 3 | SW1-SW3 |  | Active | Preferred
....4 | CADPart | 150-75266 | A1 MCO34818 | CAP CER 22PF 50V 5% C0G 0402 | AVX | 04025A220JAT2A | 0 | C6,C9 | DNP | ROHS Active | Preferred
....4 | CADPart | 150-75266 | A1 MCO34818 | CAP CER 22PF 50V 5% C0G 0402 | KEMET | C0402C220J5GAC | 0 | C6,C9 | DNP | ROHS Active | Alternate
....4 | CADPart | 150-75266 | A1 MCO34818 | CAP CER 22PF 50V 5% C0G 0402 | VENKEL COMPANY | C0402C0G500-220JNE | 0 | C6,C9 | DNP | ROHS Active | Alternate
....4 | CADPart | 150-78609 | A MCO34806 | CAP CER 10UF 10V 20% X5R 0603 | TAIYO YUDEN | LMK107BJ106MALTD | 0 | C50,C52-C54 | DNP | Active | Preferred
....4 | CADPart | 150-78609 | A MCO34806 | CAP CER 10UF 10V 20% X5R 0603 | TDK | C1608X5R1A106M | 0 | C50,C52-C54 | DNP | ROHS Active | Alternate
....4 | CADPart | 150-78609 | A MCO34806 | CAP CER 10UF 10V 20% X5R 0603 | VENKEL COMPANY | C0603X5R100-106MNP | 0 | C50,C52-C54 | DNP | ROHS Active | Alternate
....4 | CADPart | 150-75116 | A1 MCO34818 | CAP CER 18PF 50V 5% C0G 0603 | AVX | 06035A180JAT2A | 0 | C19 | DNP | ROHS Active | Alternate
....4 | CADPart | 150-75116 | A1 MCO34818 | CAP CER 18PF 50V 5% C0G 0603 | KEMET | C0603C180J5GAC | 0 | C19 | DNP | ROHS Active | Alternate
....4 | CADPart | 150-75116 | A1 MCO34818 | CAP CER 18PF 50V 5% C0G 0603 | MURATA | GRM1885C1H180JA01J | 0 | C19 | DNP | Active | Alternate
....4 | CADPart | 150-75116 | A1 MCO34818 | CAP CER 18PF 50V 5% C0G 0603 | SKYMOS | 0603CG180J500NT | 0 | C19 | DNP | ROHS Active | Alternate
....4 | CADPart | 150-75116 | A1 MCO34818 | CAP CER 18PF 50V 5% C0G 0603 | VENKEL COMPANY | C0603C0G500-180JNE | 0 | C19 | DNP | ROHS Active | Alternate
....4 | CADPart | 150-75116 | A1 MCO34818 | CAP CER 18PF 50V 5% C0G 0603 | WALSIN TECHNOLOGY CORP. | 0603N180J500LT | 0 | C19 | DNP | Active | Alternate
....4 | CADPart | 150-75116 | A1 MCO34818 | CAP CER 18PF 50V 5% C0G 0603 | YAGEO AMERICA | CC0603JRNPO9BN180 | 0 | C19 | DNP | ROHS Active | Preferred
....4 | CADPart | 150-79092 | A MCO34818 | CAP CER 10uF 16V 20% X5R 0603 | TAIYO YUDEN | EMK107BBJ106MA-T | 0 | C30,C33 | DNP | Active | Preferred
....4 | CADPart | 150-79092 | A MCO34818 | CAP CER 10uF 16V 20% X5R 0603 | TDK | C1608X5R1C106M080AB | 0 | C30,C33 | DNP | Active | Alternate
....4 | CADPart | 150-75182 | A1 MCO34818 | CAP CER 0.1UF 16V 10% X7R 0402 | CAL-CHIP | GMC04X7R104K16NT-LF | 0 | C31,C36 | DNP | Active | Alternate
....4 | CADPart | 150-75182 | A1 MCO34818 | CAP CER 0.1UF 16V 10% X7R 0402 | KEMET | C0402C104K4RAC | 0 | C31,C36 | DNP | Active | Preferred
....4 | CADPart | 150-75182 | A1 MCO34818 | CAP CER 0.1UF 16V 10% X7R 0402 | MURATA | GRM155R71C104KA88D | 0 | C31,C36 | DNP | Active | Alternate
....4 | CADPart | 150-75182 | A1 MCO34818 | CAP CER 0.1UF 16V 10% X7R 0402 | SKYMOS | 0402B104K160NT | 0 | C31,C36 | DNP | Active | Alternate
....4 | CADPart | 150-75182 | A1 MCO34818 | CAP CER 0.1UF 16V 10% X7R 0402 | TDK | C1005X7R1C104KT | 0 | C31,C36 | DNP | ROHS Active | Alternate
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

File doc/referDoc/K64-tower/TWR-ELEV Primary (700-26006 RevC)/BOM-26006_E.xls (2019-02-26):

Number | Description | BOM.Qty | BOM.Ref Des | Manufacturers.Mfr. Name | Manufacturers.Mfr. Part Number | Manufacturers.Mfr. Part Description
150-75140 | CAP CER 1000PF 50V 10% X7R 0603 | 1 | C13 | WALSIN TECHNOLOGY CORP. | 0603B102K500CT | CAP CER 1000PF 50V 10% X7R 0603
 |  |  |  | AVX | 06035C102KAT2A | CAP CER 1000PF 50V 10% X7R 0603
 |  |  |  | KEMET | C0603C102K5RAC | CAP CER 1000PF 50V 10% X7R 0603
 |  |  |  | MURATA | GRM188R71H102KA01D | CAP CER 1000PF 50V 10% X7R CC0603
 |  |  |  | VENKEL COMPANY | C0603X7R500-102KNE | CAP CER 1000PF 50V 10% X7R 0603
150-75142 | CAP CER 0.1UF 50V 10% X7R 0603 | 9 | C1,C2,C3,C4,C5,C6,C7,C9,C12 | AVX | 06035C104KAZ2A | CAP CER 0.1uF 50V 10% X7R 0603
 |  |  |  | WALSIN TECHNOLOGY CORP. | 0603B104K500CT | CAP CER 0.1UF 50V 10% X7R 0603
 |  |  |  | YAGEO AMERICA | CC0603KRX7R9BB104 | CAP CER 0.1UF 50V 10% X7R 0603
 |  |  |  | MURATA | GRM188R71H104KA93D | CAP CER 0.1UF 50V 10% X7R 0603
 |  |  |  | TDK | C1608X7R1H104KT | CAP CER 0.1UF 50V 10% X7R 0603
 |  |  |  | VENKEL COMPANY | C0603X7R500-104KNE | CAP CER 0.1UF 50V 10% X7R 0603
 |  |  |  | KEMET | C0603C104K5RAC | CAP CER 0.1UF 50V 10% X7R 0603
150-76830 | CAP ALEL 100UF 16V 20% -- CCE63X55 | 2 | C8,C11 | ELNA AMERICA INC. | RV2-16V101MSU-R | Aluminum Electrolytic Capacitor
 |  |  |  | NIPPON CHEMI-CON CORPORATION | EMVY160ADA101MF55G | CAP ALEL 100UF 16V 20% ,CCE63X55
 |  |  |  | NICHICON | UWX1C101MCL1GB | CAP ALEL 100UF 16V 20% -- CCE63X55
150-78518 | CAP TANT ESR=2.800 OHMS 10UF 16V 10% -- 3528-21 | 1 | C10 | AVX | TAJB106K016RNJ | CAP TANT ESR=2.800 OHMS 10UF 16V 10% -- 3528-21
 |  |  |  | VENKEL COMPANY | TA016TCM106KBR | CAP TANT ESR=2.800 OHMS 10UF 16V 10% -- 3528-21
180-77634 | IND FER BEAD 120 OHM@100MHZ 0.8A 25% 0805 | 2 | L1,L2 | COSMISM ELECTRONICS CORP | CB201209-121Y | IND FER BEAD 120 OHM@100MHZ 0.8A 25% 0805
210-78260 | CON 1X2 TB TH 3.5MM SP 323H SN | 1 | J10 | ON-SHORE TECHNOLOGY | ED555/2DS | CON 1X2 TB TH 3.5MM SP 323H SN
210-79486 | CON 2X40 SKT TH 2MM CTR 169H AU 91L | 2 | J8,J9 | Pinrex Enterprise Co., Ltd | 620-x2-40GB00 | CON 2X40 SKT TH 2MM CTR 169H AU 91L
 |  |  |  | Protectron Electromech (P) Ltd | P9413-80-21 | CON 2X40 SKT TH 2MM CTR 157H AU 95L
210-79515 | HDR 1X2 TH 100MIL SP 339H AU 118L | 2 | J6,J7 | SULLINS ELECTRONICS CORP | PBC01DAAN | HDR 1X2 TH 100MIL SP 338H AU 120L
 |  |  |  | Pinrex Enterprise Co., Ltd | 210-91-02GB01 | HDR 1X2 TH 100MIL SP 339H AU 118L
210-79709 | CON 164 PCI EXPRESS CRD EDGE SKT TH 1MM SP 443H AU 90L WHITE | 4 | J1,J2,J3,J4 | WIN WIN PRECISION INDUSTRIAL CO. LTD | WPES-164AN43B22UWS | CON 164 PCI EXPRESS CRD EDGE SKT TH 1MM SP 447H AU 98L WHITE
 |  |  |  | FCI | 10018783-00203TLF | CON 164 PCI EXPRESS CRD EDGE SKT TH 1MM SP 443H AU 90L WHITE
211-77242 | CON 5 USB MINI-B RA SHLD SKT SMT 31MIL SP AU | 1 | J5 | MOLEX | 0675031340 | CON 5 USB MINI-B RA SHLD SKT SMT 31MIL SP AU
 |  |  |  | HIROSE | UX60-MB-5S8 | CON 5 USB MINI-B RA SHLD SKT SMT 31MIL SP AU
280-75694 | MOUNTING HOLE CIRC DRILL 125 CIRC PAD 175 PLATED TRHU HOLE, no part to order | 4 | BH1,BH2,BH3,BH4
315-78812 | IC VREG LDO 3.3V 1.5A DPAK | 1 | U1 | ST MICROELECTRONICS | LD1086DT33TR | IC VREG LDO 3.3V 1.5A DPAK
370-76468 | LED SUPER AMBER SGL 30MA 0805 | 1 | D7 | Bright Led Electronics Corp | BL-HJF35A-TRB | LED SUPER AMBER SGL 30MA 0805
370-76469 | LED SUPER ORANGE RED SGL 30MA 0805 | 1 | D6 | Bright Led Electronics Corp | BL-HJE35A-TRB | LED SUPER ORANGE RED SGL 30MA 0805
470-30301 | RES MF 560 1/10W 5% 0603 | 1 | R1 | YAGEO AMERICA | RC0603JR-07560RL | RES MF 560 OHM 1/10W 5% 0603
 |  |  |  | KOA SPEER | RK73B1JTTD561J | RES MF 560 OHM 1/10W 5% 0603
 |  |  |  | VENKEL COMPANY | CR0603-10W-561JT | RES MF 560 OHM 1/10W 5% 0603
 |  |  |  | WALSIN TECHNOLOGY CORP. | WR06X561JTL | RES MF 560 OHM 1/10W 5% 0603
470-75451 | RES MF 330 OHM 1/10W 5% 0603 | 1 | R2 | VENKEL COMPANY | CR0603-10W-331JT | RES MF 330 OHM 1/10W 5% 0603
 |  |  |  | VISHAY INTERTECHNOLOGY | CRCW0603330RJNEA | RES MF 330 OHM 1/10W 5% 0603
 |  |  |  | PANASONIC | ERJ3GEYJ331V | RES MF 330 OHM 1/10W 5% 0603
 |  |  |  | BOURNS | CR0603-JW-331ELF | RES MF 330 OHM 1/10W 5% 0603
 |  |  |  | WALSIN TECHNOLOGY CORP. | WR06X331JTL | RES MF 330 OHM 1/10W 5% 0603
 |  |  |  | KOA SPEER | RK73B1JTTD331J | RES MF 330 OHM 1/10W 5% 0603
480-76978 | DIODE SCH 1A 20V MICROSMP SMT | 2 | D2,D8 | VISHAY INTERTECHNOLOGY | MSS1P3L-M3/89A | DIODE SCH 1A 20V MICROSMP SMT
480-77942 | DIODE TVS 163A 5V 1500W DO-214AB | 1 | D3 | SeCoS Halbleitertechnologie GmbH | SMCJ5.0A | DIODE TVS 163A 5V 1500W DO-214AB
 |  |  |  | LITTLEFUSE | SMCJ5.0A | DIODE TVS 163A 5V 1500W DO-214AB
480-77943 | DIODE SCH 8A 30V TO-277A | 1 | D5 | VISHAY INTERTECHNOLOGY | SS8P3L-M3/86A | DIODE SCH 8A 30V TO-277A
480-77958 | DIODE SCH PWR RECT 1A 20V SOD323 | 2 | D1,D4 | SeCoS Halbleitertechnologie GmbH | SCS120V | DIODE SCH PWR RECT LOW VF 1A 20V SOD323
510-75117 | FUSE PLYSW 2.6A HOLD 6V SMT ROHS | 1 | F1 | TYCO ELECTRONICS | MINISMDC260F-2 | FUSE PLYSW 2.6A 6V SMT
510-77735 | SW SPDT SLD CNTR RA 5A 125VAC TH | 1 | SW1 | Salecom Electronics Co., Ltd | TS-14P-A1-2-Q-E-H | SW SPDT SLD CNTR RA 5A 125VAC TH

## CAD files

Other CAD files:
doc/referDoc/datasheet/ArduinoUno.dxf

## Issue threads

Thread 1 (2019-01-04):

WUT-4-3-5投板测试问题

whutddk, 2019-01-04:
* 贴片型PMOD不适合这种非U盘型大板
     - 强度不够
* PMOD阻挡了USB电源口，需要破拆，，，
* 有源蜂鸣器焊环太小，掉焊盘了

whutddk, 2019-01-05:
* 三色led封装断货
* 无合适底座

whutddk, 2019-01-12:
## Power good error
* R50 7.5K 估计值太大了 led几乎不亮，
* 且为负逻辑

whutddk, 2019-01-18:
USB,TF卡外壳没有接地

Closed 2019-12-20.

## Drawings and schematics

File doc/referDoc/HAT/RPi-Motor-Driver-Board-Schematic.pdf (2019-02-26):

# POWER

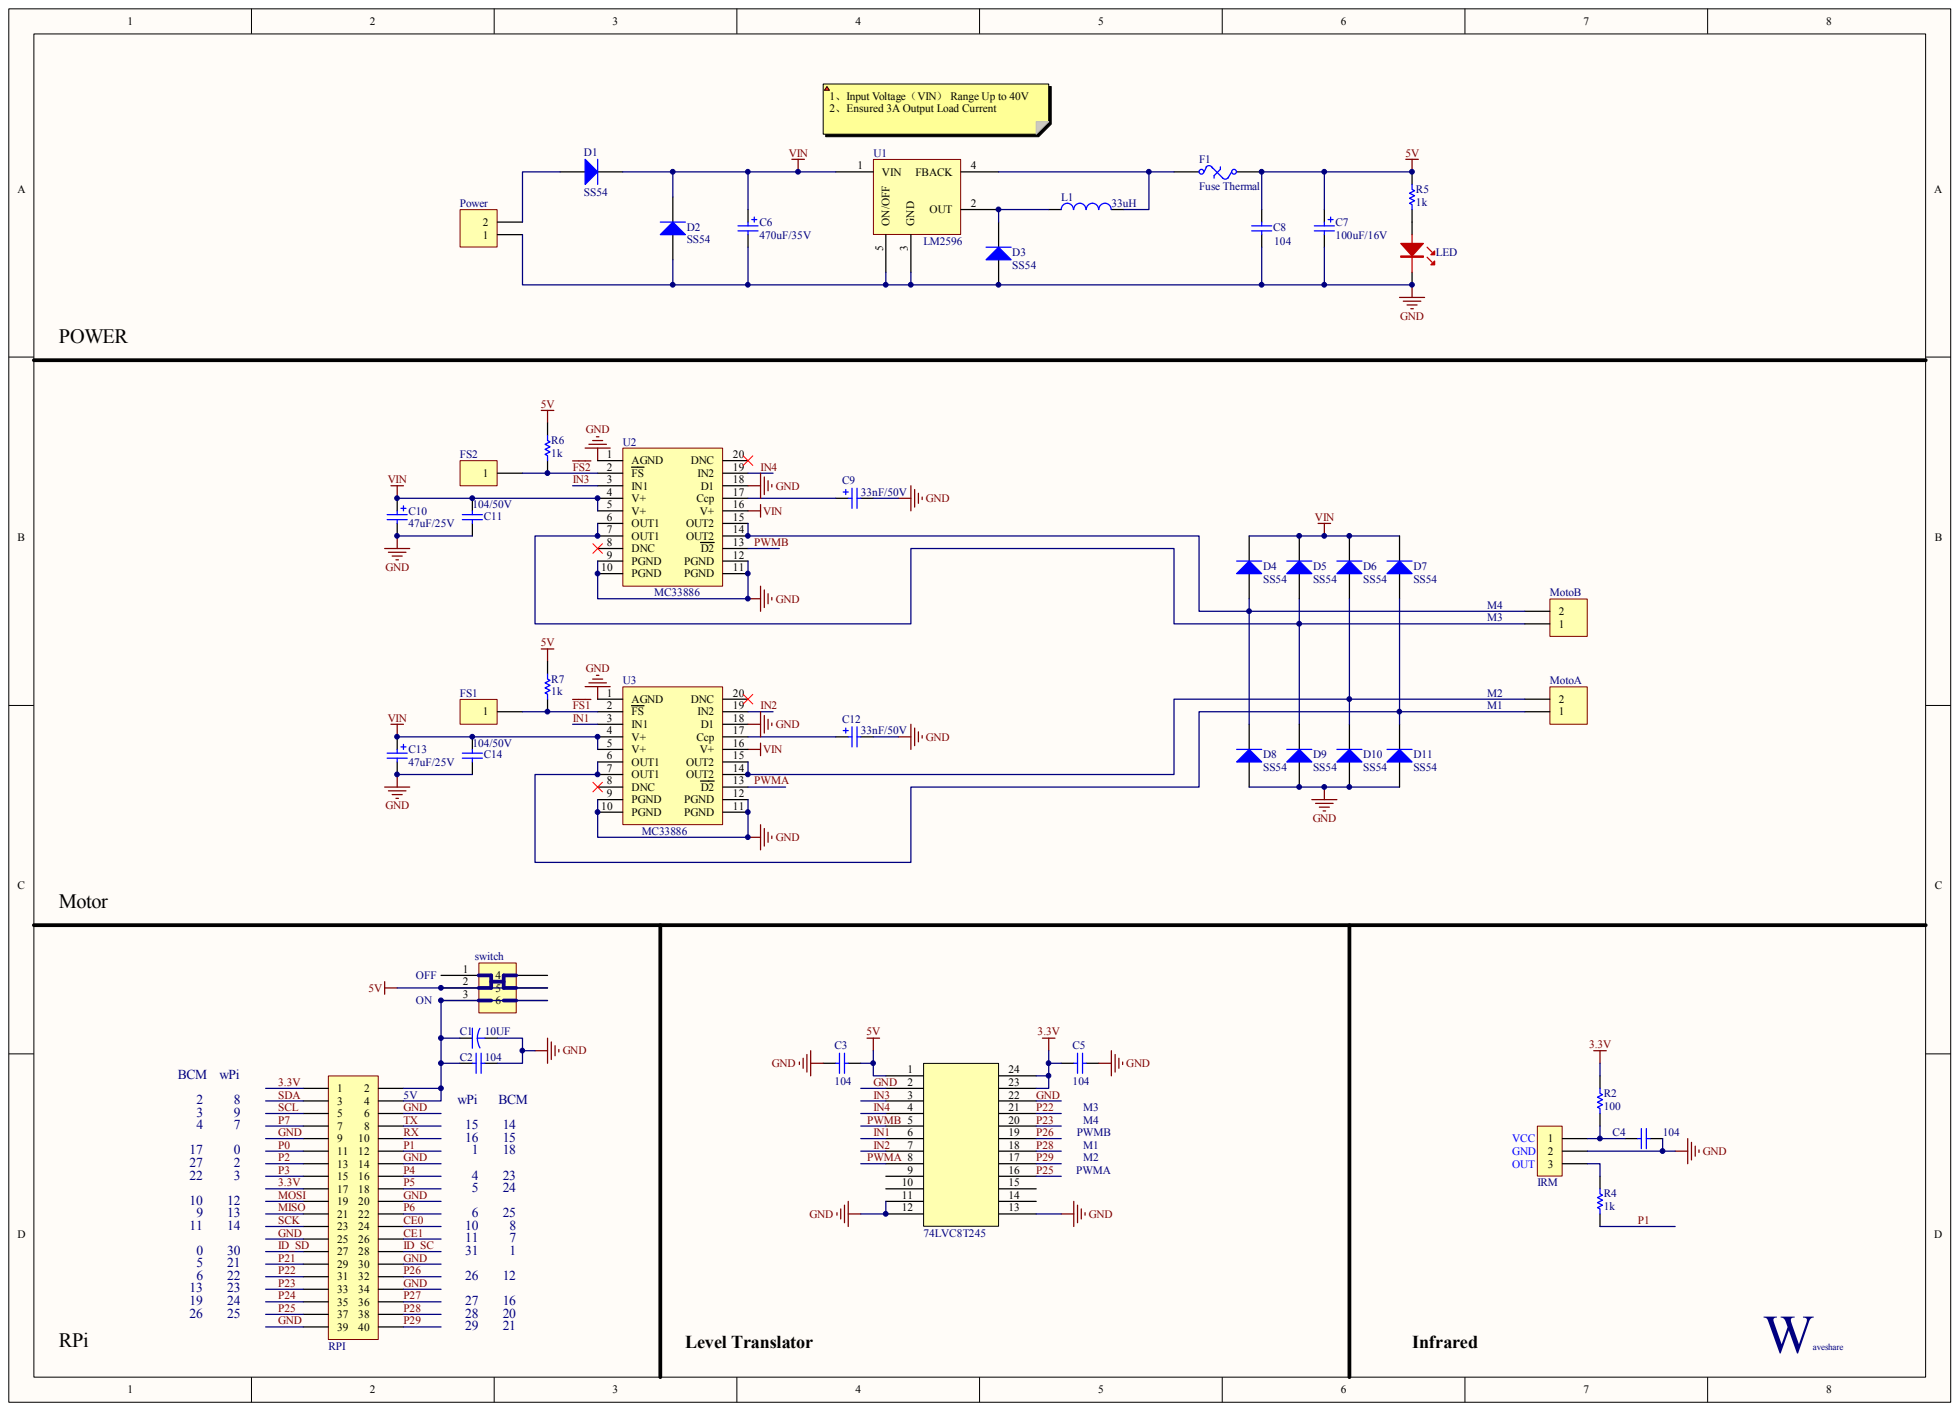
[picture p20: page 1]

1、Input Voltage（VIN） Range Up to 40V
2、Ensured 3A Output Load Current

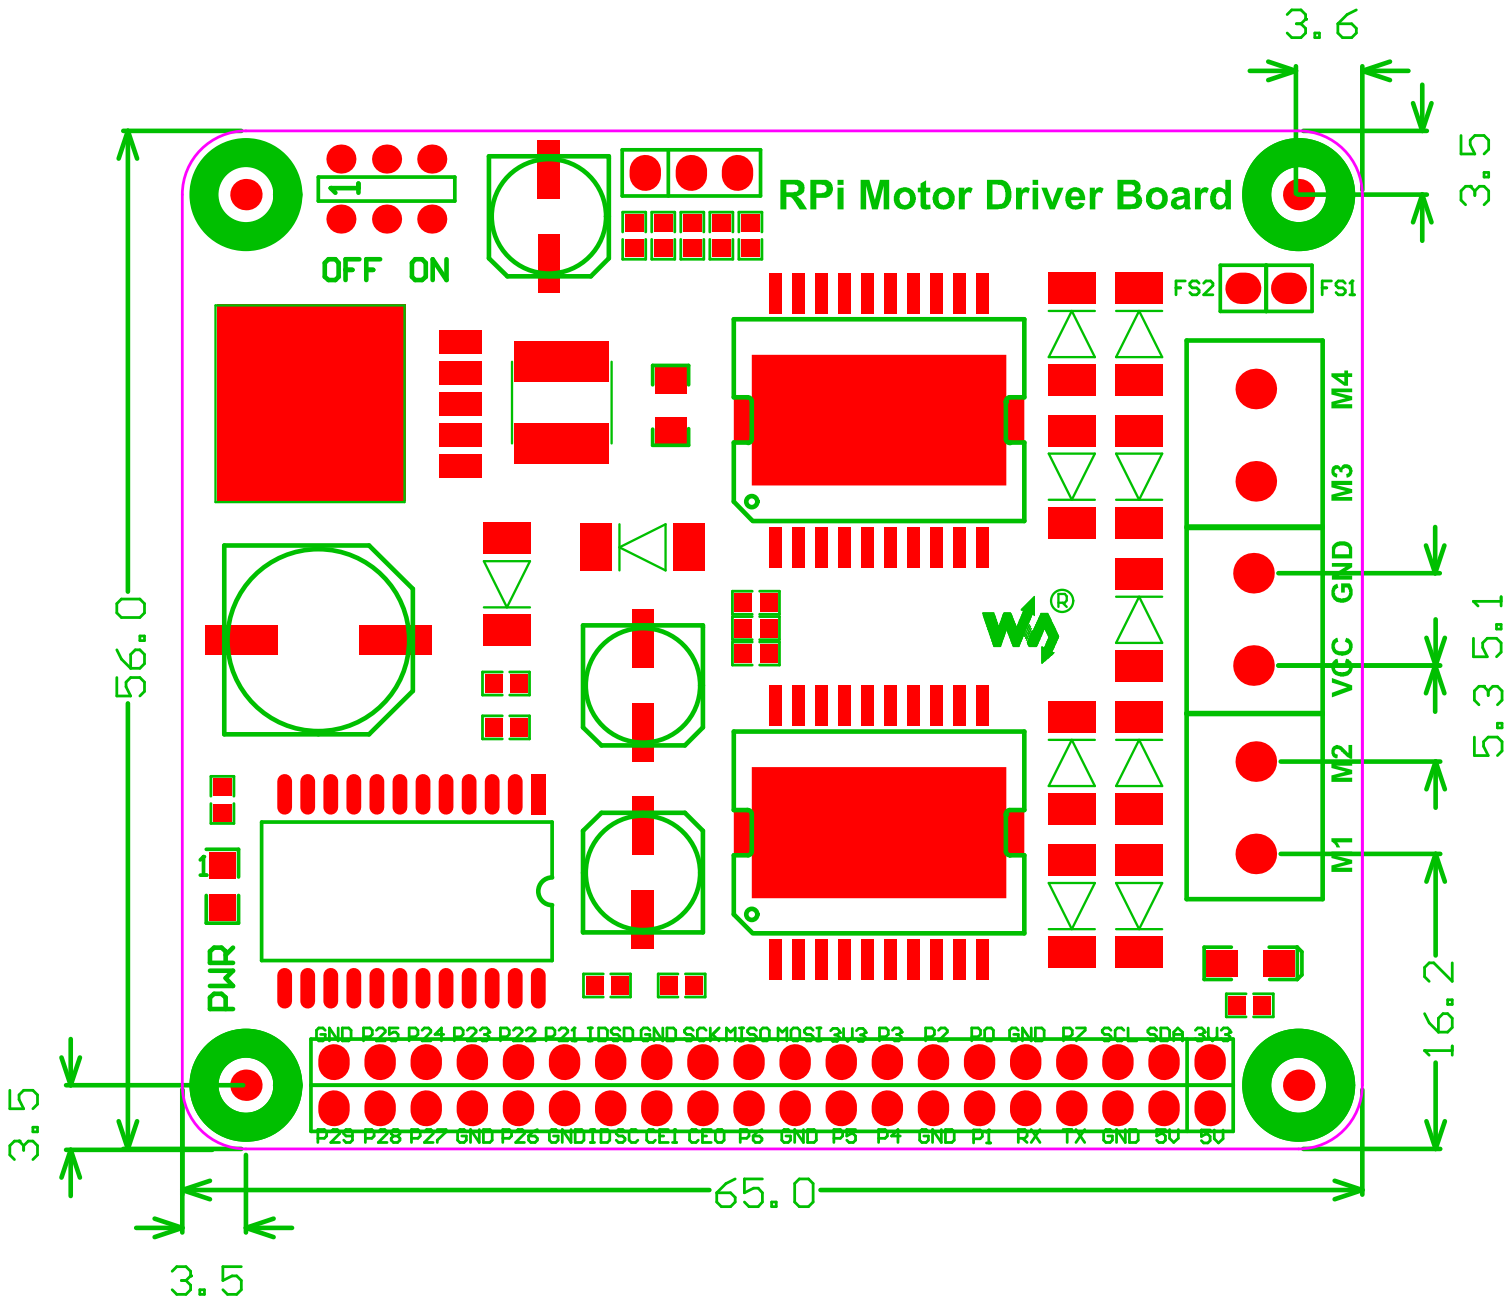
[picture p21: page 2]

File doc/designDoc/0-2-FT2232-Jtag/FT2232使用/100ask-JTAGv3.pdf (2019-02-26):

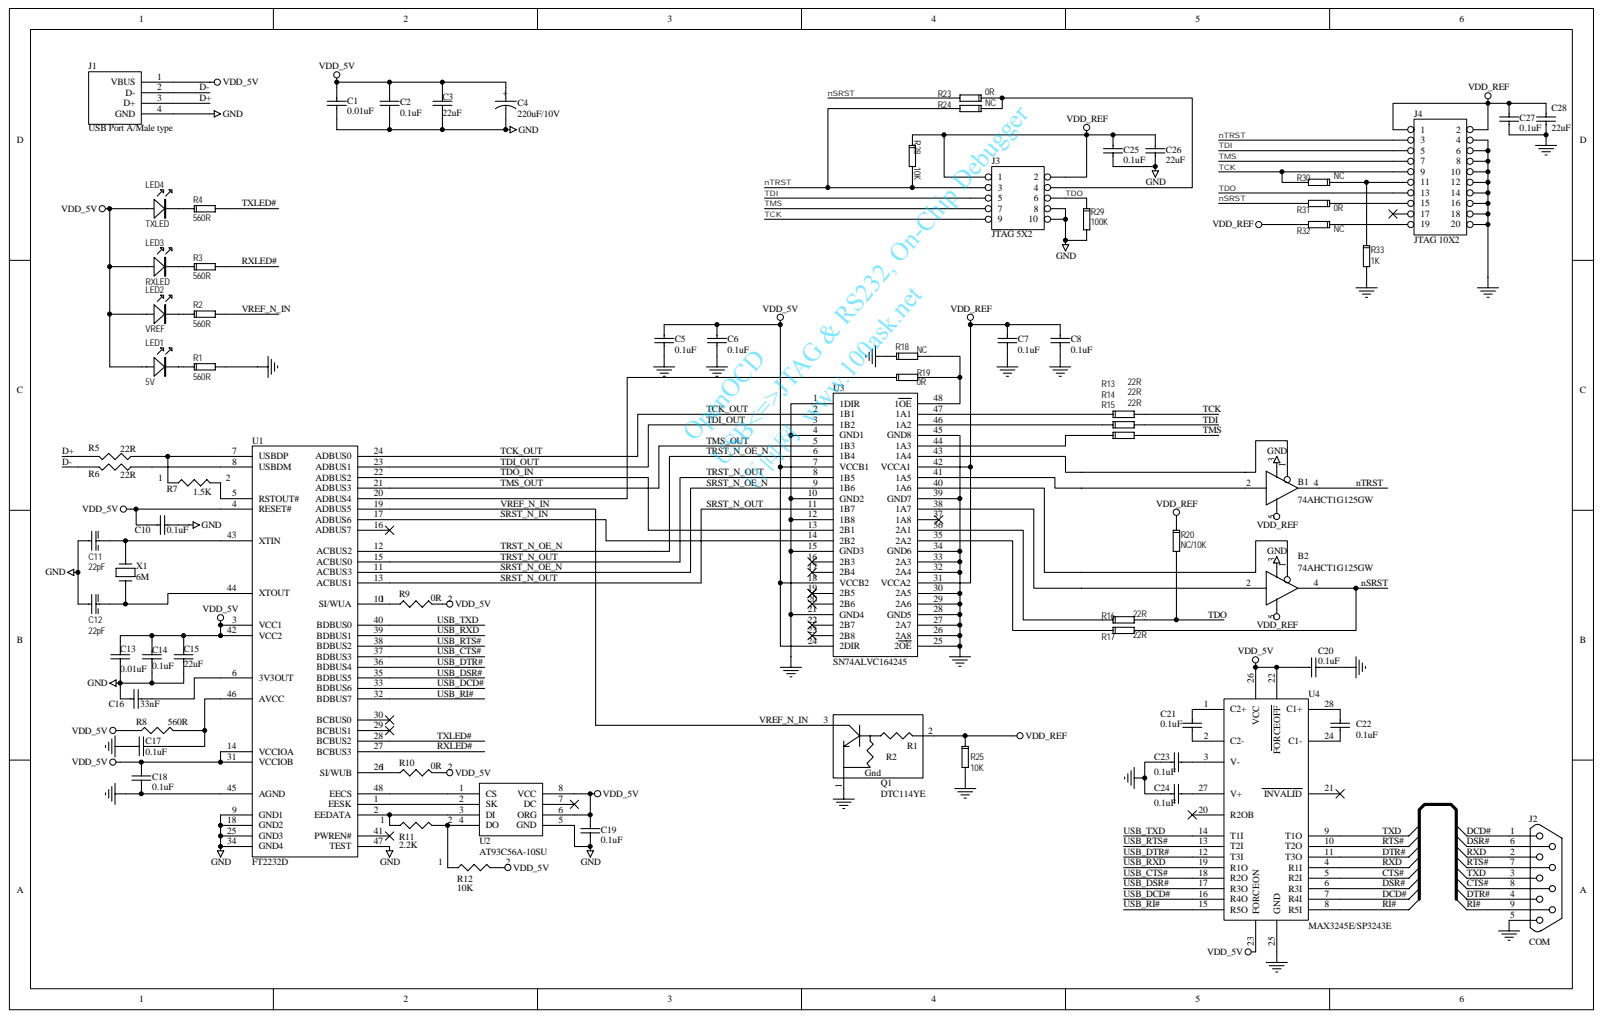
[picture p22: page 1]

USB Port A/Male type

USB<=>JTAG & RS232, On-Chip Debugger

TDI_OUT | 1B2 3 | TDI
TMS_OUT | GND1 4 | TMS

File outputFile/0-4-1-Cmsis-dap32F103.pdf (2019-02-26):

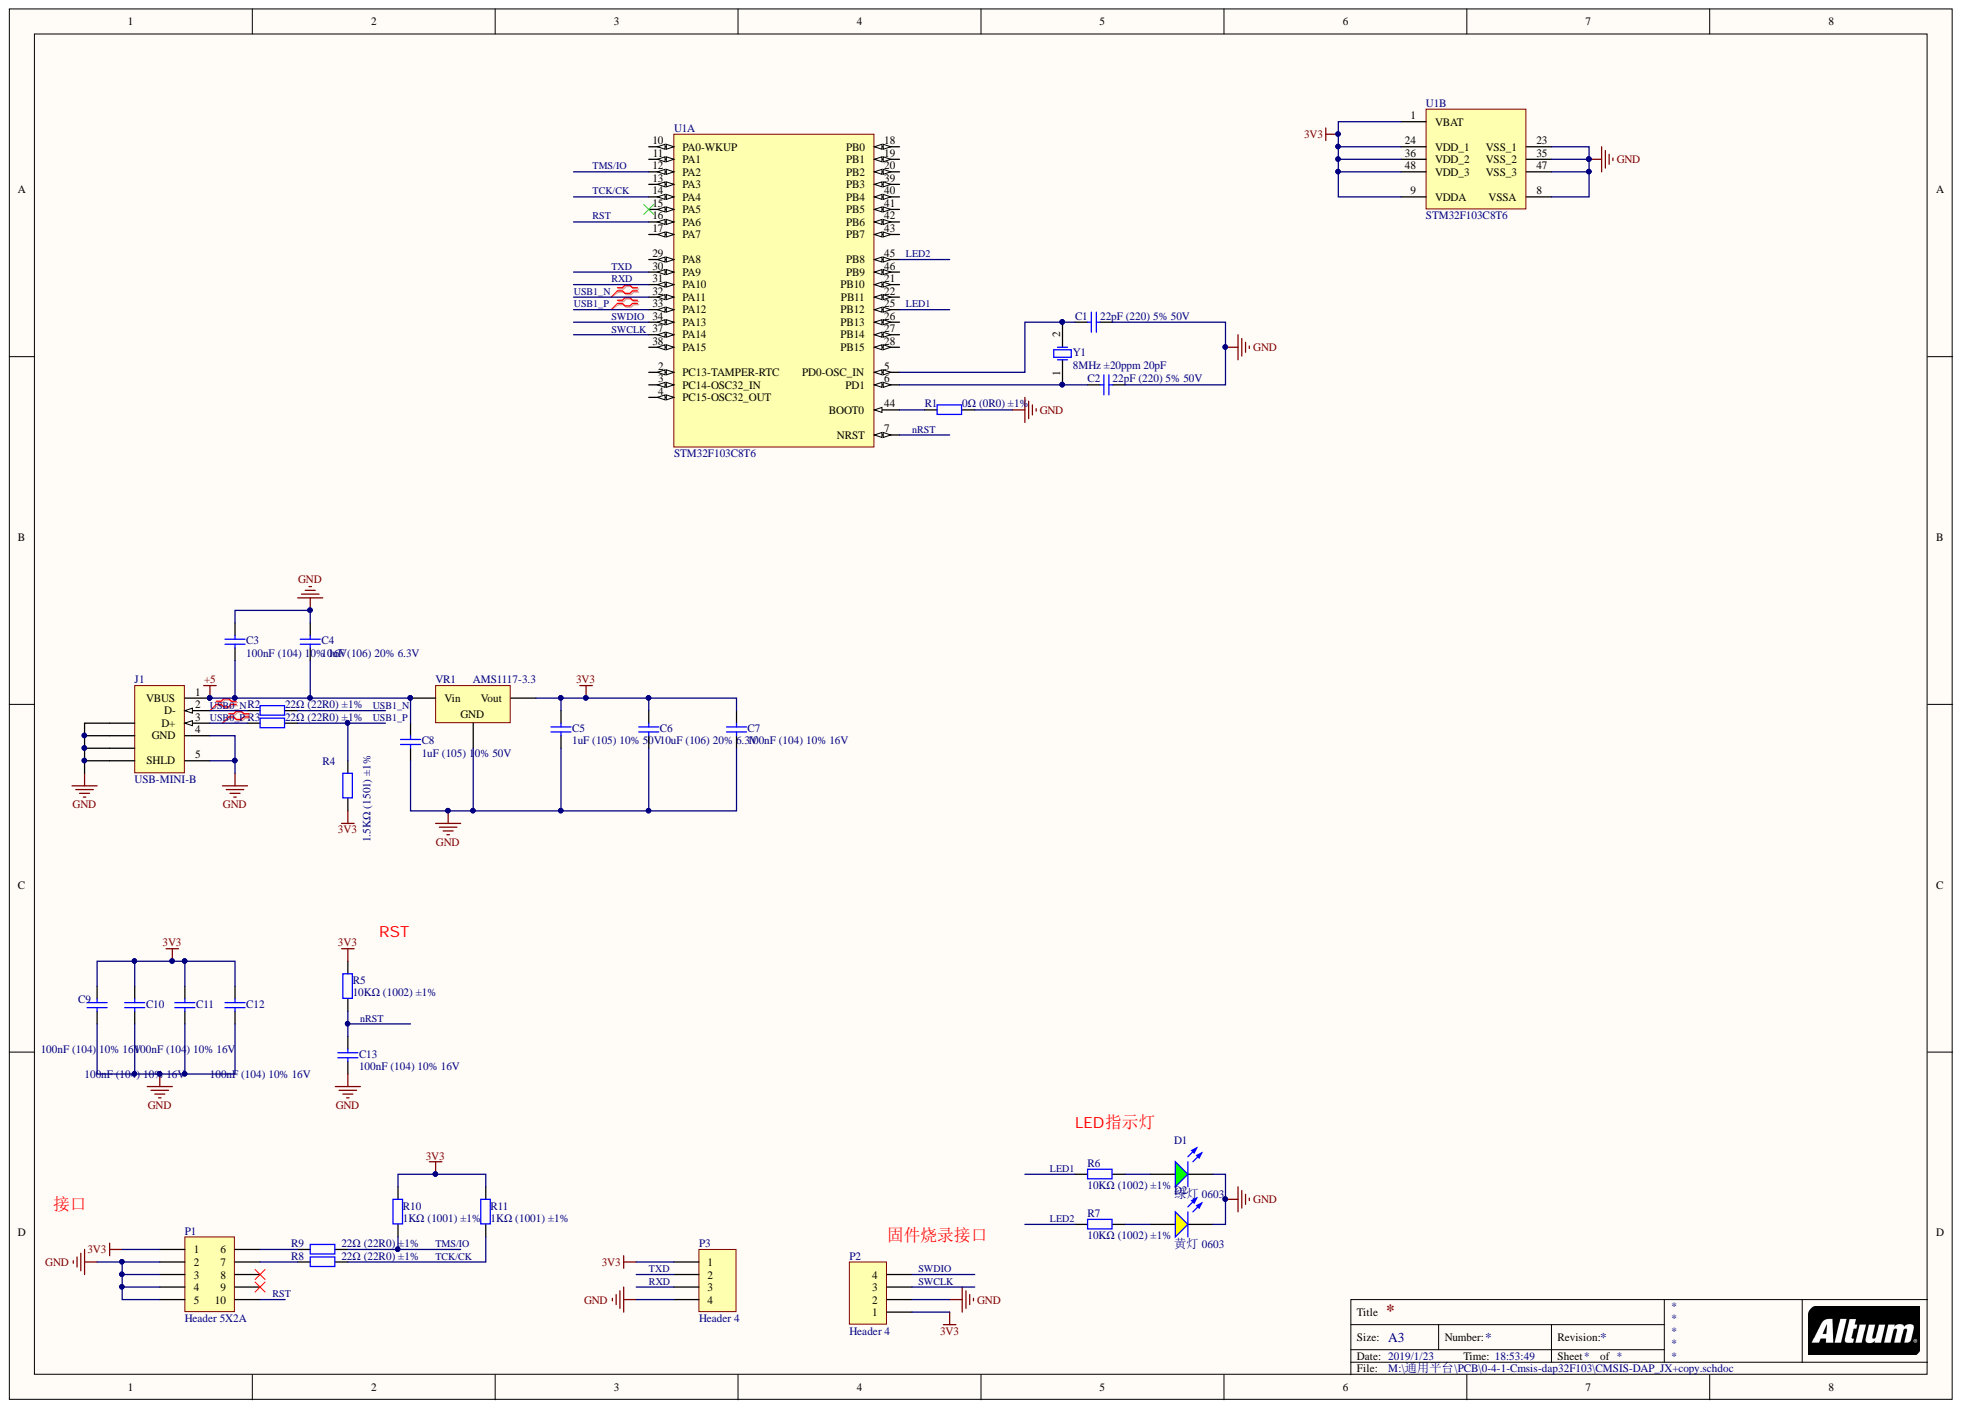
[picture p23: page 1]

* Title | * * * * *

Size: A3 | Number: * | Revision: *
Date: 2019/1/23 Time: 18:53:49 | | Sheet * of *

M:\通用平台\PCB\0-4-1-Cmsis-dap32F103\CMSIS-DAP_JX+copy.schdoc
File:

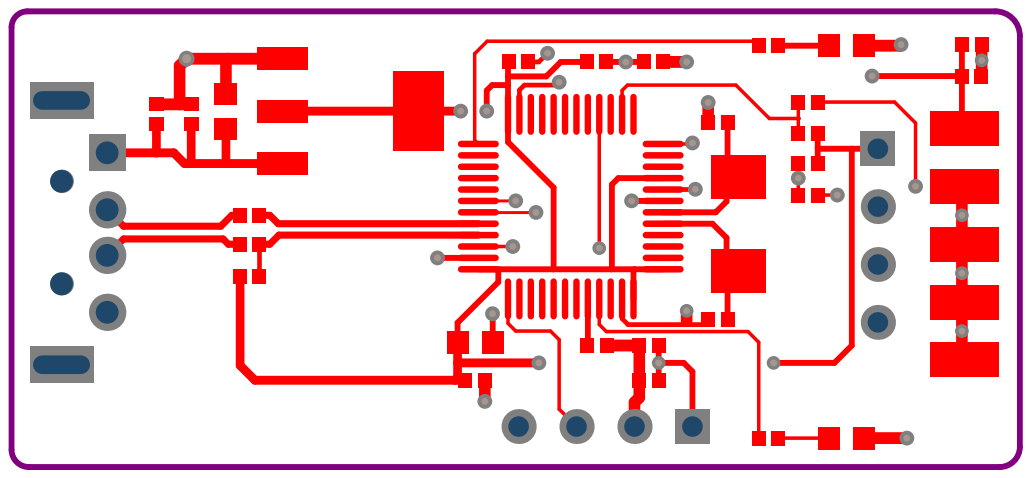
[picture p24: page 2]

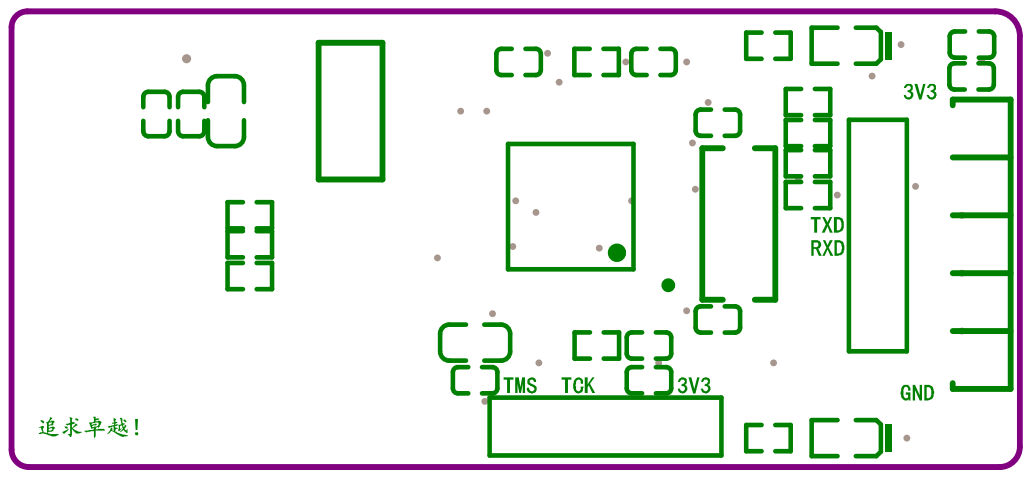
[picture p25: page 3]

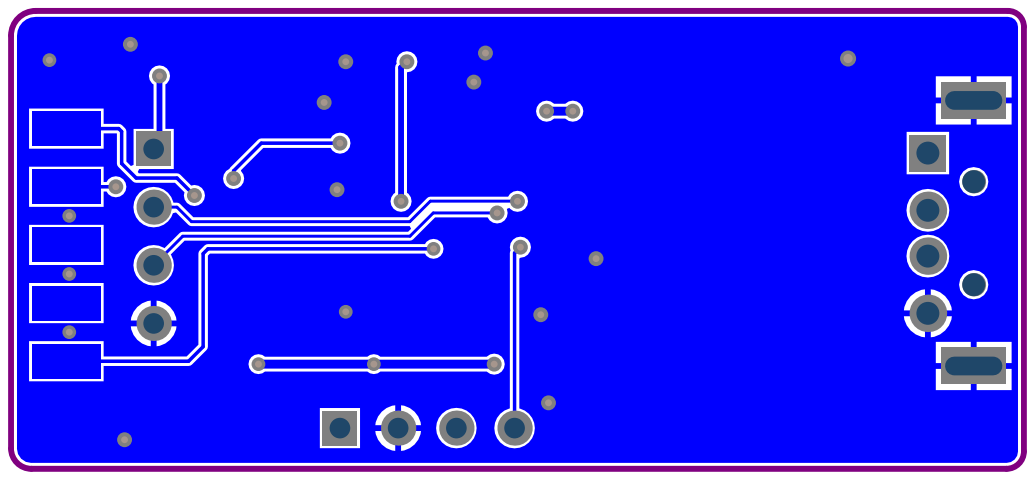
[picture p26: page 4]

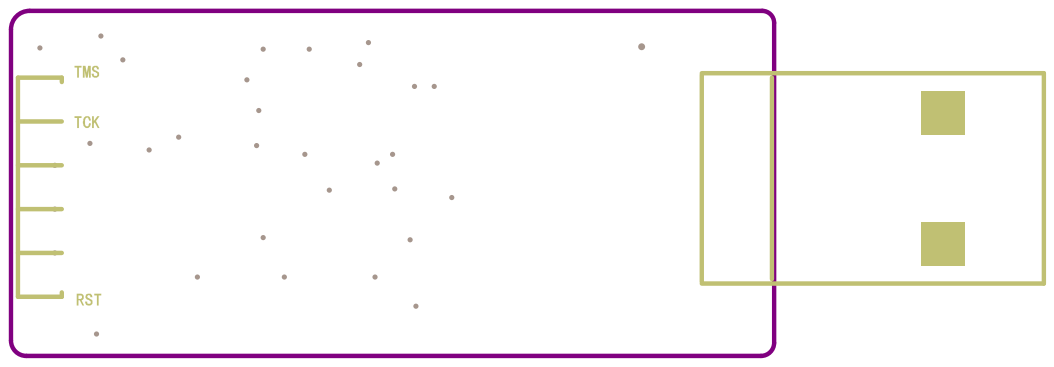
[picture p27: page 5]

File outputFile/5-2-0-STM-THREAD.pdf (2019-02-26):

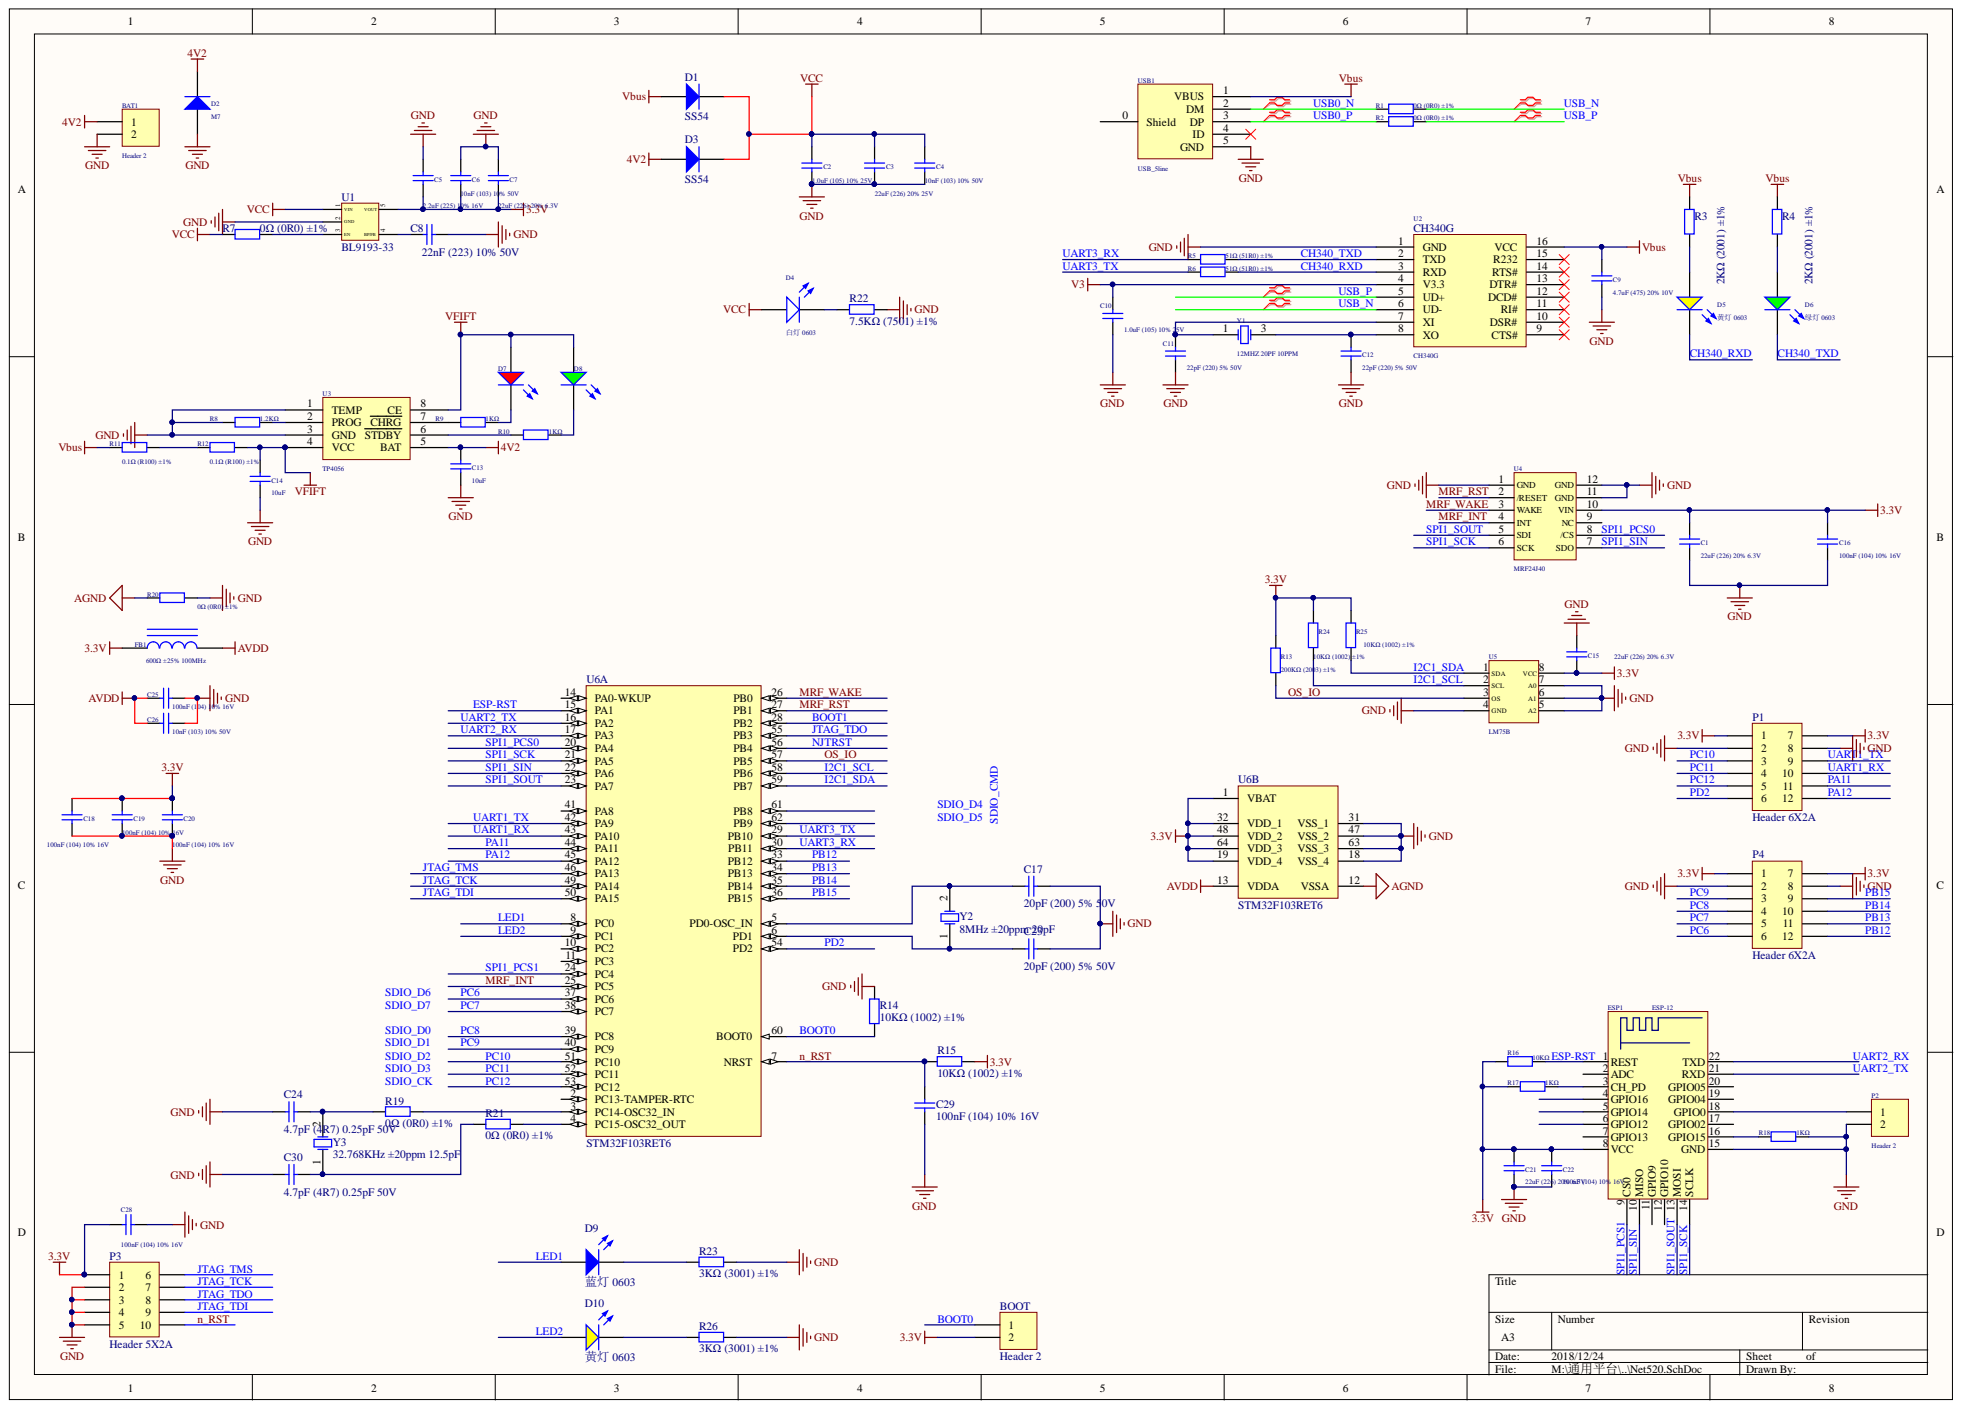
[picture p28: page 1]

PC1 9 | 8MHz ±20ppm 20pF
PC2 10 | PD2

SCLK 14 GND 15 GPIO15 16 GPIO02 17 GPIO0 18 GPIO04 19 GPIO05 20 RXD 21 TXD 22

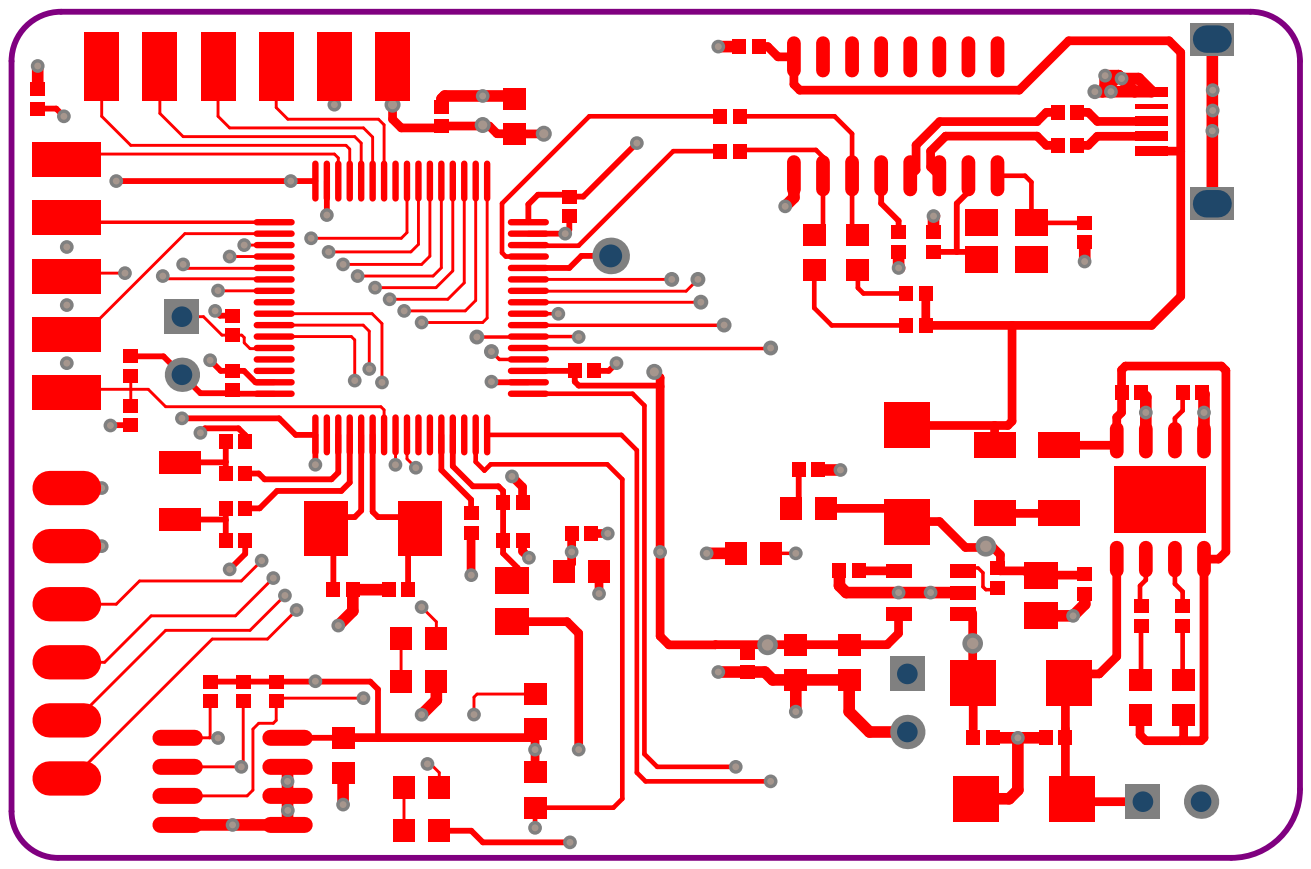
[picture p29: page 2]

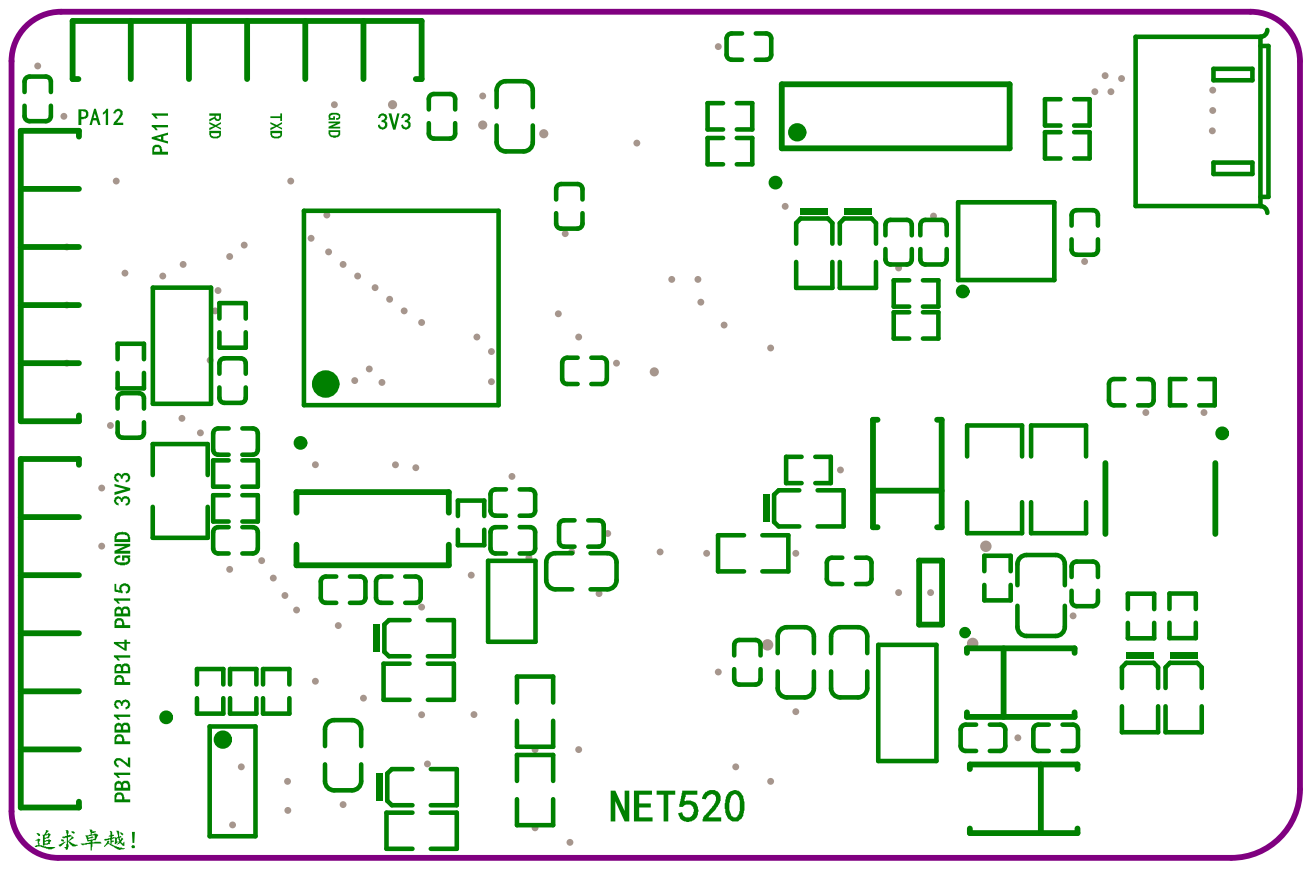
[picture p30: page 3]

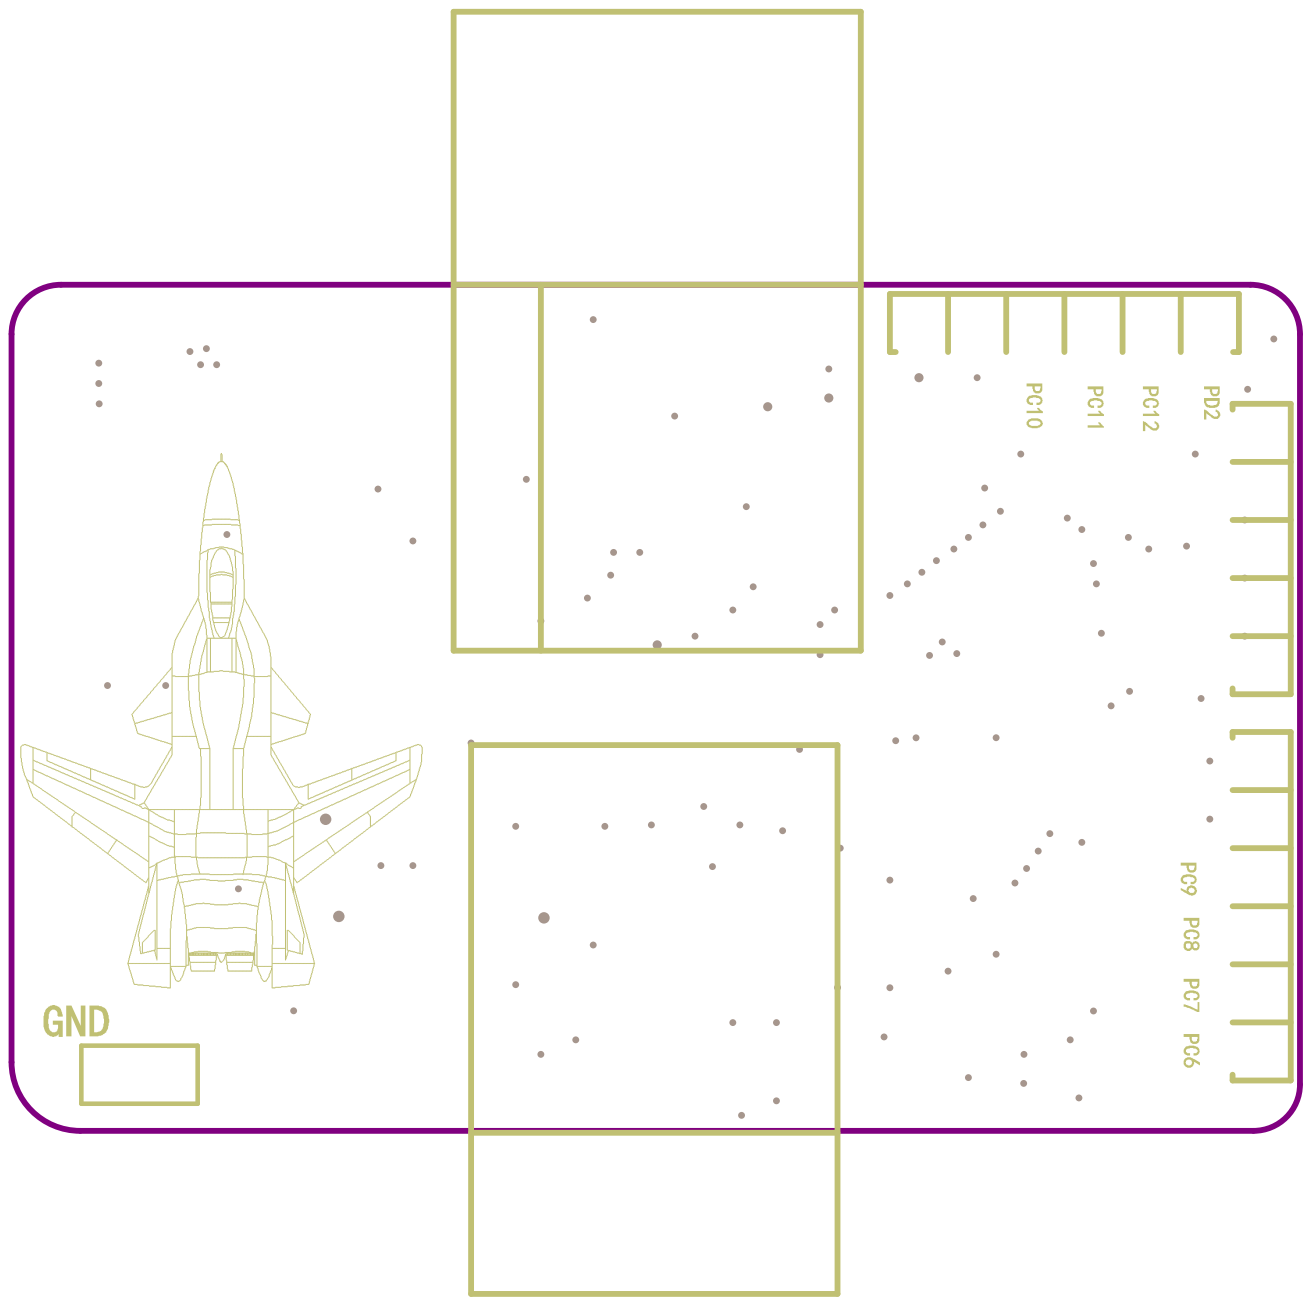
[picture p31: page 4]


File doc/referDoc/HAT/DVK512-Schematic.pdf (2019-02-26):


INT 3

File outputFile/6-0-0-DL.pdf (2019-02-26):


EESK 1

R12 | EEDATA 2

EECLK
EEDATA










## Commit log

2019-02-26 通用平台验证型
    [ArduinoUno.dxf, BOM-26006_E.xls, BOM-26493_A.xls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]
2019-02-26 期末输出设计文件
    [flexplatV1.0.PrjPCB]
2019-02-26 引脚清查
    [FPv0.1.PcbDoc, FPv0.11.PcbDoc, FPv0.12.PcbDoc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]
2019-02-26 功能受改用144BGA
    [connect.SchDoc]
2019-02-26 基本扇出
    [MCU.SchDoc, RAM.SchDoc, USB.SchDoc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]
2019-02-26 讨论外设扩展
    [FPv1.3.1.PcbDoc, USB.SchDoc, connect.SchDoc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]
2019-02-26 切回patch
    [FPv1.3.1.PcbDoc]
2019-02-26 修正封装等待收尾
    [FPv1.3.1.PcbDoc, MCU.SchDoc, RAM.SchDoc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]
2019-02-26 全局布通
    [FPv1.3.1.PcbDoc, MCU.SchDoc, RAM.SchDoc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]
2019-02-26 修正长度
    [FPv1.3.1.PcbDoc]
2019-02-26 开始绕等长
    [FPv1.3.1.PcbDoc, MCU.SchDoc]
2019-02-26 等长绕完
    [FPv1.3.1.PcbDoc]
2019-02-26 允许开始收尾
    [FPv1.3.1.PcbDoc, MCU.SchDoc, RAM.SchDoc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]
2019-02-26 布线完毕，开始敲丝印
    [FPv1.3.1.PcbDoc, USB.SchDoc, flexplatV1.3.PrjPCB]
2019-02-26 丝印敲完，放logo
    [FPv1.3.1.PcbDoc]
2019-02-26 等待发出
    [FPv1.3.2.PcbDoc, flexplatV1.3.PrjPCB]
2019-02-26 可制造性失败，撤回
    [FPv1.3.1.PcbDoc]
2019-02-26 修正扇出
    [FPv1.3.1.PcbDoc, flexplatV1.3.PrjPCB]
2019-02-26 二次尝试投板
    [FPv1.3.2.PcbDoc]
2019-02-26 正式投出
    [FPv1.3.1.PcbDoc, FPv1.3.2.PcbDoc]
2019-02-26 投板确认
    [flexplatV1.3.PrjPCB]
2019-02-26 输出配置文件
    [flexplatV1.3.PrjPCB]
2019-02-26 PLANE直通，开始打补丁
    [FPv1.3.1.PcbDoc, FPv1.3.2.PcbDoc, flexplatV1.3.PrjPCB]
2019-02-26 修改槽孔
    [flexplatV1.3.PrjPCB]
2019-02-26 二次投板
    [FPv1.3.5.PcbDoc, flexplatV1.3.PrjPCB]
2019-02-26 生成pdf文件
    [FPv1.3.5.PcbDoc, catalog.SchDoc, flexplatV1.3.PrjPCB]
2019-02-26 format file system
    [ArduinoUno.dxf, BOM-26006_E.xls, BOM-26493_A.xls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]
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2019-02-26 FPGA最小系统框架
    [FPGA.SchDoc, FPV0-3.PrjPCB, GENERAL-IO.SchDoc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]
2019-02-26 原理图基本成型
    [FPGA_CONFIG.SchDoc, FPGA_IO.SchDoc, FPGA_POWER.SchDoc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]
2019-02-26 暂时挂起
    [FPV0-3.PcbDoc, GENERAL-IO.SchDoc]
2019-02-26 增加封装
    [FPV0-3.PrjPCB, Schlib.SchLib]
2019-02-26 基本完成bank14扇出
    [FPGA_IO.SchDoc, FPV0-3.PcbDoc]
2019-02-26 主要外设扇出
    [FPV0-3.PcbDoc]
2019-02-26 电源测试板
    [FPV0-3.PcbDoc, POWER.SchDoc, POWER_TS.SchDoc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]
2019-02-26 upload POWER TESET 1
    [PWTS.PcbDoc, PWTS.PrjPCB, PWTSout.PcbDoc]
2019-02-26 较大失误，编号混乱了
    [FPGA_CONFIG.SchDoc, FPGA_IO.SchDoc, FPGA_POWER.SchDoc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]
2019-02-26 try to fix
    [FPGA_CONFIG.SchDoc, FPGA_IO.SchDoc, FPGA_POWER.SchDoc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]
2019-02-26 不太成功，基本修复
    [FPV0-3.PcbDoc, GENERAL-IO.SchDoc]
2019-02-26 fix all
    [FPV0-3.PcbDoc]
2019-02-26 推进艰难
    [FPGA_CONFIG.SchDoc, FPV0-3.PcbDoc, GENERAL-IO.SchDoc]
2019-02-26 开始放置电容
    [FPGA_IO.SchDoc, FPGA_POWER.SchDoc, FPV0-3.PcbDoc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]
2019-02-26 重新扇出
    [FPV0-3.PcbDoc, GENERAL-IO.SchDoc]
2019-02-26 外围扇出
    [FPV0-3.PcbDoc]
2019-02-26 布1v0电容
    [FPV0-3.PcbDoc]
2019-02-26 布3V3内核电容
    [FPV0-3.PcbDoc]
2019-02-26 扇出基本完成
    [FPGA_IO.SchDoc, FPV0-3.PcbDoc, GENERAL-IO.SchDoc]
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2019-02-26 周末交换设备
    [FPGA_CONFIG.SchDoc, FPGA_IO.SchDoc]
2019-02-26 双ldo测试
    [LDOTEST.PcbDoc, LDOTEST.PcbLib, LDOTEST.PrjPCB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]
2019-02-26 信号线束修正AD
    [FPGA_CONFIG.SchDoc, FPGA_IO.SchDoc, FPV0-3.PcbDoc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]
2019-02-26 除去FT2232
    [USB.SchDoc]
2019-02-26 拨乱反正
    [FPGA_POWER.SchDoc, FPV0-3.PcbDoc, POWER.SchDoc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]
2019-02-26 大规模调线
    [FPV0-3.PcbDoc]
2019-02-26 电源布完
    [FPV0-3.PcbDoc]
2019-02-26 基本布完，开始适配嘉力创规则
    [FPV0-3.PcbDoc, GENERAL-IO.SchDoc]
2019-02-26 基本布完了
    [FPV0-3.PcbDoc, GENERAL-IO.SchDoc, POWER.SchDoc]
2019-02-26 布线优化
    [FPGA_CONFIG.SchDoc, FPGA_IO.SchDoc, FPV0-3.PcbDoc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]
2019-02-26 布线完成
    [FPV0-3.PcbDoc, FPV0-3.PrjPCB, GENERAL-IO.SchDoc]
2019-02-26 试投嘉立创
    [FPV0-3.PcbDoc]
2019-02-26 电源大规模保护
    [POWER.SchDoc]
2019-02-26 丝印完成
    [FPGA_IO.SchDoc, FPV0-3.PcbDoc, FPV0-3.PrjPCB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]
2019-02-26 输出PDF
    [FPV0-3.PrjPCB, catalog.SchDoc]
2019-02-26 加入上拉电阻到jtag“
    [FPGA_CONFIG.SchDoc, FPV0-3.PrjPCB]
2019-02-26 测试通过
    [FPV0-3.PrjPCB]
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2019-02-26 打开项目
    [FPGA_CONFIG.SchDoc, FPGA_IO.SchDoc, FPGA_POWER.SchDoc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]
2019-02-26 使用大封装K64，标志FB引脚
    [MCU.SchDoc]
2019-02-26 删除fb独立地址位
    [FPGA_IO.SchDoc, MCU.SchDoc]
2019-02-26 项目重命名
    [FPW1-0-0.PrjPCB]
2019-02-26 K64fb扇出
    [FPGA_CONFIG.SchDoc, FPGA_IO.SchDoc, FPGA_POWER.SchDoc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]
2019-02-26 FPGA扇出
    [FPW1-0-2.PcbDoc]
2019-02-26 Flexbus布通
    [FPGA_IO.SchDoc, FPW1-0-0.PrjPCB, FPW1-0-2.PcbDoc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]
2019-02-26 修改flexbus
    [FPGA_CONFIG.SchDoc, FPGA_IO.SchDoc, FPW1-0-0.PrjPCB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]
2019-02-26 扇出SRAM
    [FPGA_CONFIG.SchDoc, FPGA_IO.SchDoc, FPW1-0-2.PcbDoc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]
2019-02-26 spi下载
    [FPGA_CONFIG.SchDoc, FPW1-0-0.PrjPCB, MCU.SchDoc]
2019-02-26 考虑io扇出方法
    [FPGA_IO.SchDoc, FPW1-0-2.PcbDoc, GENERAL-IO.SchDoc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]
2019-02-26 定义接口
    [FPW1-0-2.PcbDoc, GENERAL-IO.SchDoc, MCU.SchDoc]
2019-02-26 布shiel-B
    [FPW1-0-0.PrjPCB, GENERAL-IO.SchDoc, MCU.SchDoc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]
2019-02-26 MCU扇出完成
    [FPW1-0-2.PcbDoc, GENERAL-IO.SchDoc, MCU.SchDoc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]
2019-02-26 io基本布置完成，还差电源，最后io布置，常用、外设
    [FPGA_CONFIG.SchDoc, FPGA_IO.SchDoc, FPW1-0-0.PrjPCB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]
2019-02-26 io布完
    [FPGA_IO.SchDoc, FPW1-0-2.PcbDoc, GENERAL-IO.SchDoc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]
2019-02-26 所有外设布置完
    [FPW1-0-2.PcbDoc, GENERAL-IO.SchDoc, MCU.SchDoc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]
2019-02-26 剩下电源
    [FPGA_CONFIG.SchDoc, FPGA_POWER.SchDoc, FPW1-0-2.PcbDoc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]
2019-02-26 开始最后清理，冷却
    [FPGA_IO.SchDoc, FPW1-0-0.PrjPCB, FPW1-0-2.PcbDoc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]
2019-02-26 logo准备
    [FPW1-0-2.PcbDoc, catalog.SchDoc]
2019-02-26 comment #IKK7P 颜色修正
    [FPGA_IO.SchDoc, FPW1-0-0.PrjPCB, FPW1-0-2.PcbDoc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]
2019-02-26 comment #IKK7O 还差logo
    [FPGA_CONFIG.SchDoc, FPGA_IO.SchDoc, FPW1-0-2.PcbDoc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]
2019-02-26 SRAM拉线
    [FPW1-0-0.PrjPCB, FPW1-0-2.PcbDoc]
2019-02-26 Flexbus拉线
    [FPW1-0-2.PcbDoc]
2019-02-26 resolved #IKK7N
    [FPW1-0-2.PcbDoc]
2019-02-26 敲入logo
    [FPW1-0-0.PrjPCB, FPW1-0-2.PcbDoc]
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2019-02-26 usb问题
    [Net510.SchDoc, NetV510.PrjPCB]
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2019-02-26 开始谋划修正板
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2019-02-26 check file system format
    [FPGA_CONFIG.SchDoc, FPGA_IO.SchDoc, FPGA_POWER.SchDoc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]
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2019-02-26 bugfix:designer in note error logo:delete BB-8
    [FPGA_CONFIG.SchDoc, FPGA_IO.SchDoc, WUT-4-3-3.PrjPCB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]
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
